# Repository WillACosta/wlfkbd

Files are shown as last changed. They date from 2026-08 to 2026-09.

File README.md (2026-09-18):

## The Wolf Split Keyboard

> [!WARNING]
> **Work In Progress (WIP)**: This project is currently under active development.

> 3×6 (+2 outer-pinky) Split Keyboard · 3 Thumb Keys · All 1U · MX Compatible

The **WᛝLF Keyboard**, or simply **wlfkbd**, is a 40-key keyboard
featuring only 2 outer-pinky keys to improve ergonomics. This keyboard takes inspiration from well-known open-source keyboards such as "Corne", "Klor", and "Delta/Omega".

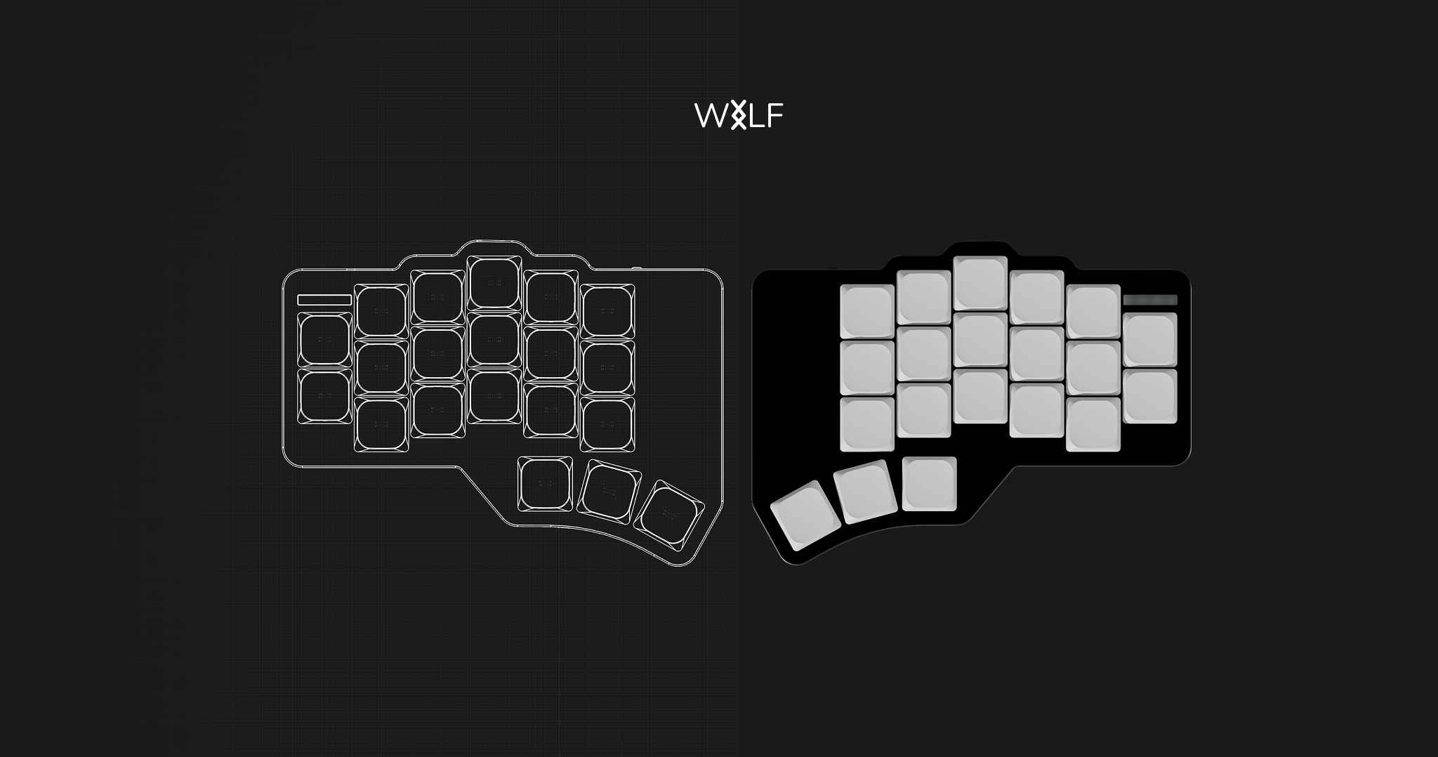
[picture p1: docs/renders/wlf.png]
"The Wolf Keyboard Render"


### Core Features

- Wireless BLE (XIAO nRF52840).
- Ultra-low-profile build (<= 8mm).
- Low-profile switches and keycaps.
- Compatible with MX-Standard and Gateron KS33/3.0 Low-Profile switches.
- Good battery life (>=700mAh).
- Minimalist and industrial design.
- Aluminum case.
- MX-Spacing.
- White backlight.
- RGB Status LEDs.

> For details about the features, head to the [specs module](./docs/specs/)

## Firmware & Keymap

The firmware for The Wolf is powered by [ZMK](https://zmk.dev/) and is maintained in its dedicated repository: **[WillACosta/zmk-config-wlf](https://github.com/WillACosta/zmk-config-wlf)**

This repository links the firmware as a Git submodule under [`firmware/`](https://github.com/WillACosta/zmk-config-wlf). To clone both the hardware designs and firmware together:

```bash
git clone --recurse-submodules https://github.com/WillACosta/wlfkbd.git
```

## Layout Overview

| Zone | Columns | Rows | Keys/half | Notes |
|---|---|---|---|---|
| Matrix | 6 (outer → inner) | 3 (bottom, home, top) | 17 | Outer column skips bottom row (2 keys only) |
| Thumb | 3 (inner, home, outer) | 1 | 3 | Splayed arc, anchored below index |
| **Total** | | | **20** | **40 keys full board** |

### Column Stagger Profile

```
         outer  pinky  ring   middle  index  inner
stagger:   —    +u/2   +u/4   +u/4   −u/4   −u/4
mm:        0    +9.525 +4.763 +4.763 −4.763 −4.763
```

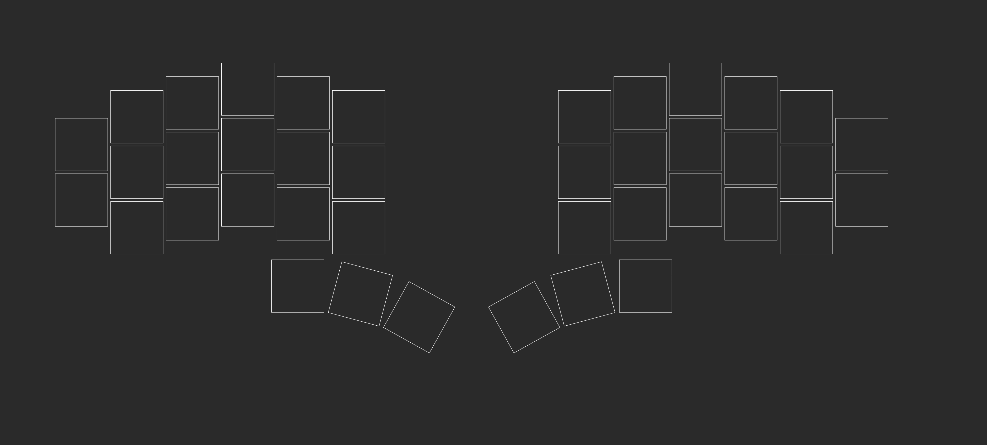
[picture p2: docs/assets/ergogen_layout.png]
"Ergogen wlfkbd Layout"


**Thumb Cluster Geometry**

| Key | Splay | Spread | Stagger | Effective rotation |
|-----|---|---|---|---|
| thumb_inner | 0° | u (19.05mm) | 0mm | 0° |
| thumb_home | −15° | u+2.5 (21.55mm) | −2.7mm | −15° |
| thumb_outer | −14° | u+2.5 (21.55mm) | −2.5mm | −29° |

The thumb cluster anchors at `matrix_index_bottom` with a `[-0.1u, -1.30u]` offset, placing it slightly left and well below the index column — a natural resting position for the thumb.

> See the Ergogen [config file here](./keyboard/ergogen/config.yml) (used only for the layout diagram)

## Motivations

After stepping into the rabbit hole of "Custom Split Keyboards", I found myself fascinated by this new world of different keyboard layouts, techniques, and a lot of fun!

I have used and own some beloved models created by incredible people, including:

- [Corne](https://github.com/foostan/crkbd)
- [Klor](https://github.com/GEIGEIGEIST/KLOR)
- [Delta/Omega](https://github.com/unspecworks/delta-omega)
- [Lily58](https://github.com/kata0510/Lily58)

The Corne is my favorite keyboard out there (you may notice some similarities between the wlfkbd and crkbd).

Still, I was missing something—that little thing that would improve my experience with the keyboard. Then I started testing different layouts on paper and came up with the layout shown earlier. I even used [Ergo Pad](https://pashutk.com/ergopad/) to find the most comfortable way of typing for my long fingers.

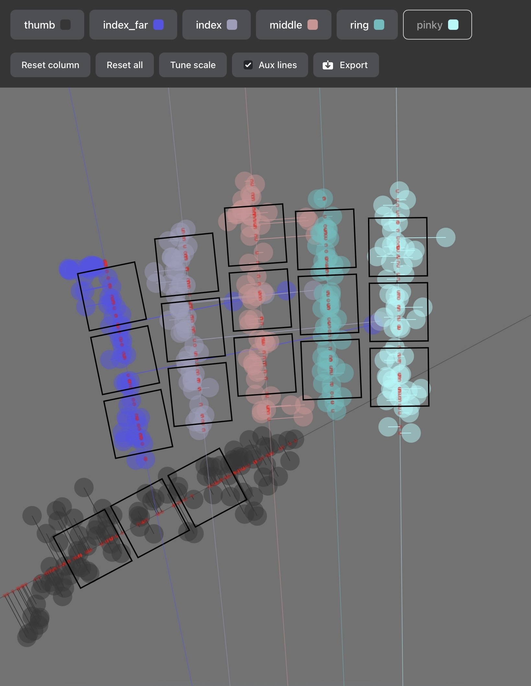
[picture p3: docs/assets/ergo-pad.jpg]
"Ergo-Pad layout tester"


### Features

I'm very fond of good, minimal design, so I've taken inspiration from Apple products, especially the [Magic Keyboard](https://www.ifixit.com/Teardown/Magic+Keyboard+Teardown/50995) and [Magic Trackpad](https://www.ifixit.com/Teardown/Magic+Trackpad+2+Teardown/51032).

I really enjoy the white backlight of the built-in Mac keyboard, so I wanted to implement this in the first revision. Even though I only use the backlight occasionally, it's a nice-to-have for me.

The major feature I present here is the status LED on top of the outer-pinky column. It's something that I really wanted to have in previous keyboards but hadn't.

Take a look at the current 3D render of the keyboard:

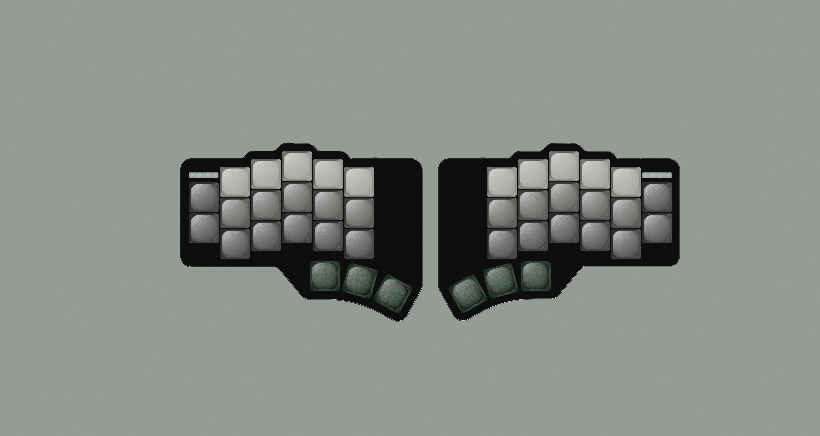
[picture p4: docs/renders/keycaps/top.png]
3D render for the wlfkbd


> For more pictures head to the [render gallery](./docs/renders/)

## Why "The WᛝLF"?

I really enjoy the symbolism of Wolves, it reminds me of the raw aspect of being human and a strong connection with nature and solitude. Regarding the Norse rune, the "Inguz", it represents "transitions", "new beginnings", "a force of will", etc. I have it tattooed on my right arm, so it's also a personal reference.

## PCB Design

The PCB was built to be ordered already assembled. This means that all components are SMD, so while you may be able to solder them by hand, it requires solid soldering experience.

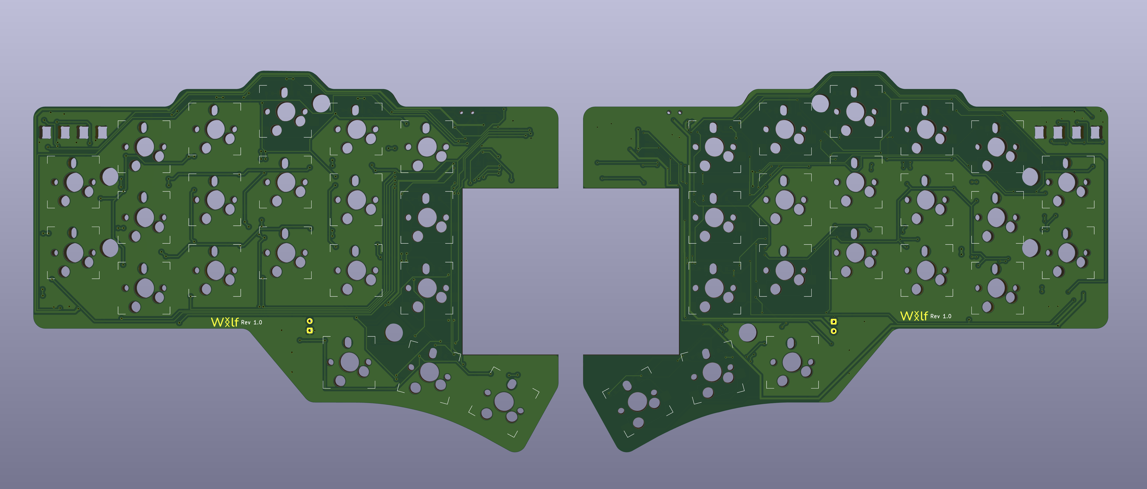
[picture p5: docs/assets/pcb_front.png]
PCB render front

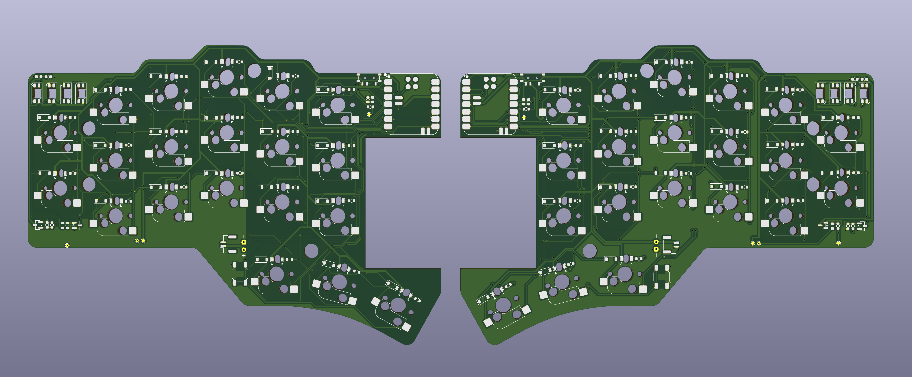
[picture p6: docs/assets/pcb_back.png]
PCB render back


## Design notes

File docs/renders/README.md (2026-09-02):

# Render Gallery

A unified visual gallery of 3D renders, views, and wireframes for the **wlfkbd** (Wolf Split Keyboard).

## Perspectives & Angles

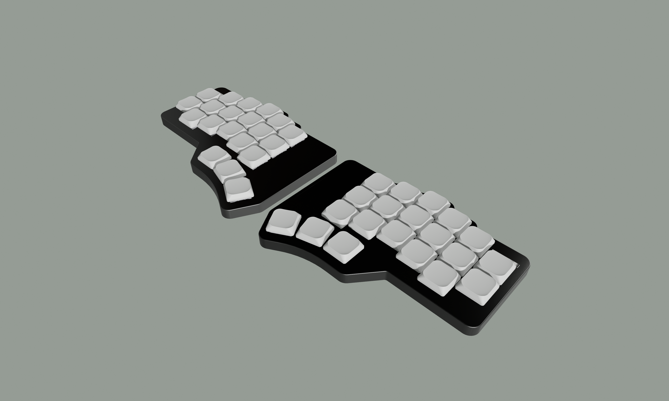
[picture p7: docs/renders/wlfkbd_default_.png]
Default View


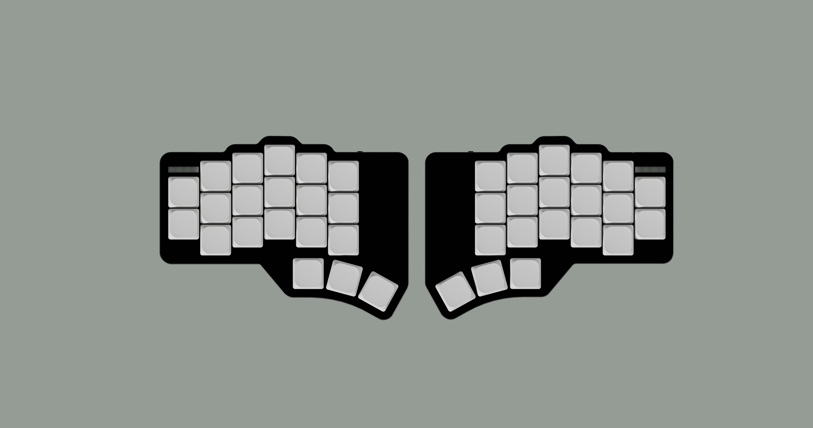
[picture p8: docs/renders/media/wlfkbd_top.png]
Top View


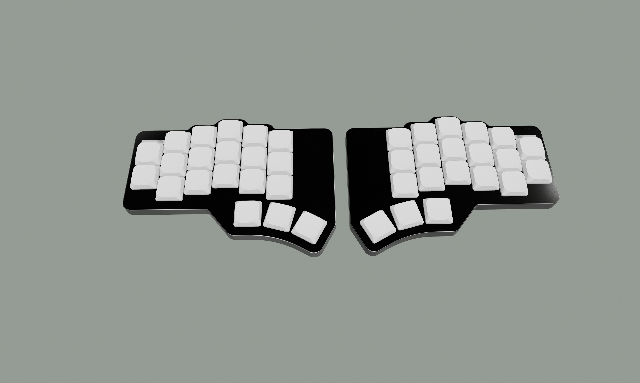
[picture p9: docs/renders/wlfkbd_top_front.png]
Top Front View


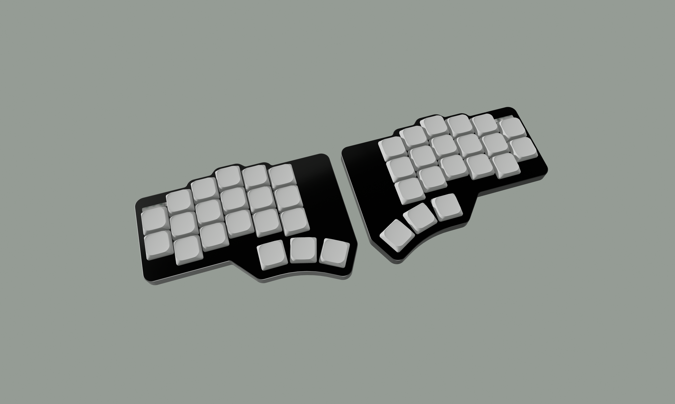
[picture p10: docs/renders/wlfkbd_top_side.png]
Top Side View


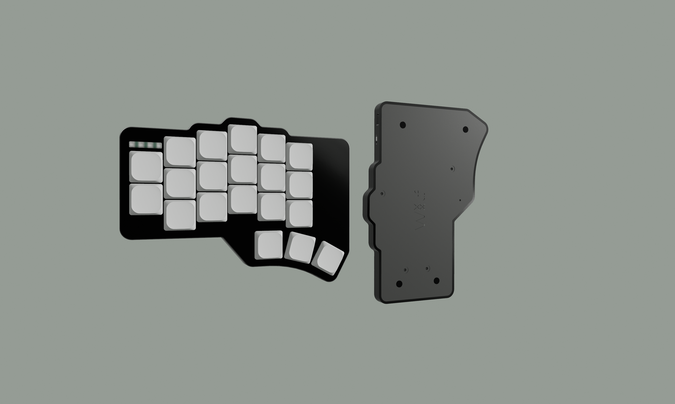
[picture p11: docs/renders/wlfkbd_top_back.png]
Top Back View


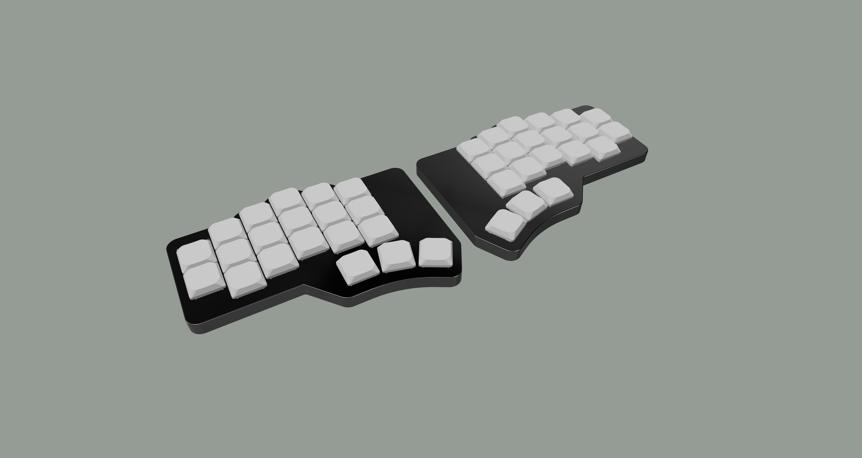
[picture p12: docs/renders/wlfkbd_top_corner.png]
Top Corner View


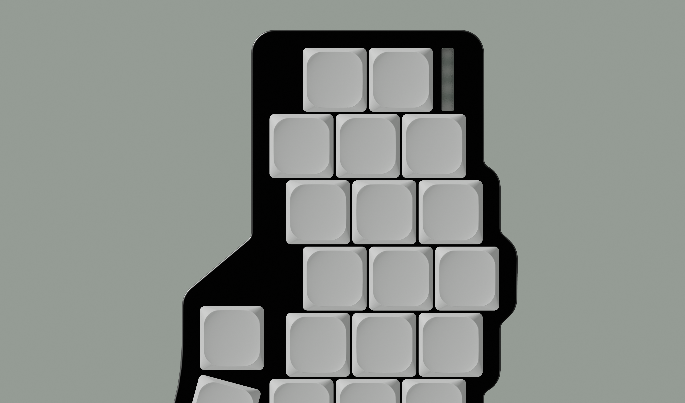
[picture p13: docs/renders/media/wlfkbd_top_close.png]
Top Close View


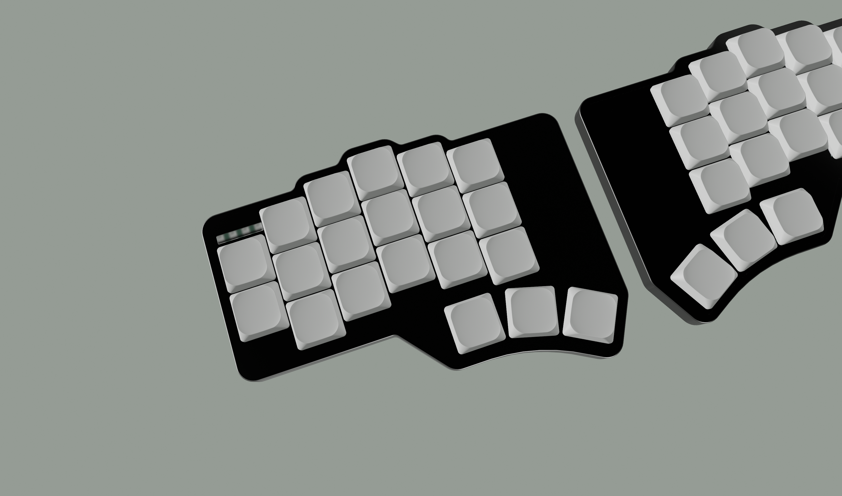
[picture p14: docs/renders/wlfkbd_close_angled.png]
Close Angled View


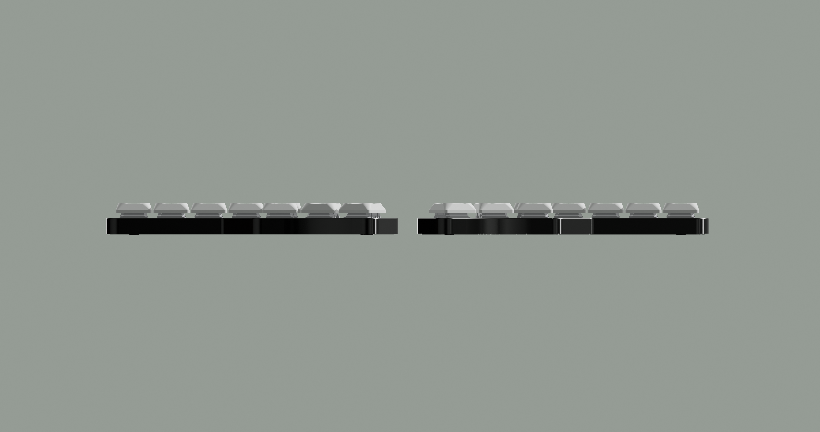
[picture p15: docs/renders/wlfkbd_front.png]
Front View


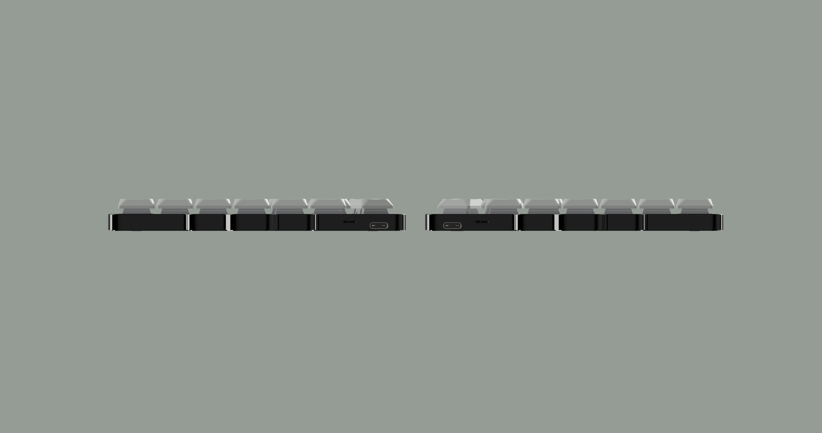
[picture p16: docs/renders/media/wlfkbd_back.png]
Back View


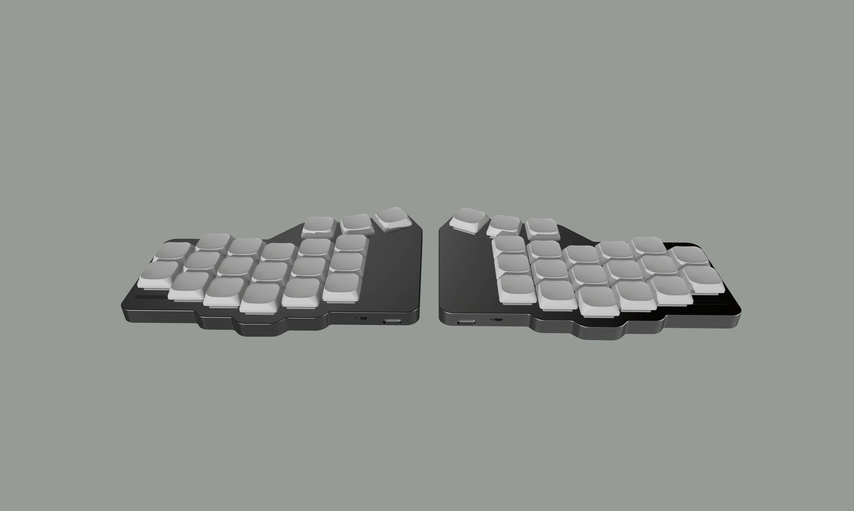
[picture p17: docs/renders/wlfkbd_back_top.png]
Back Top View


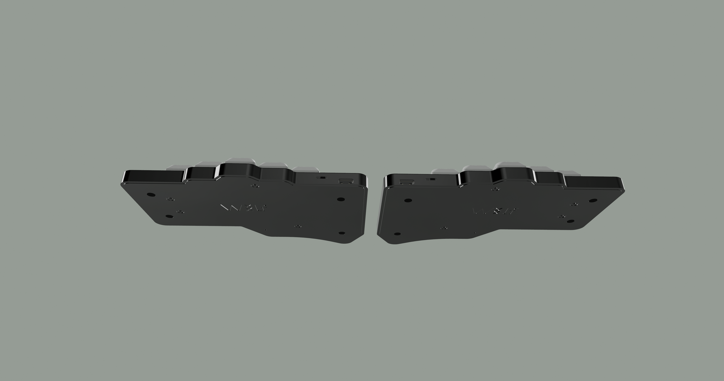
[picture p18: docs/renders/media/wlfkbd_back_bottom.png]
Back Bottom View


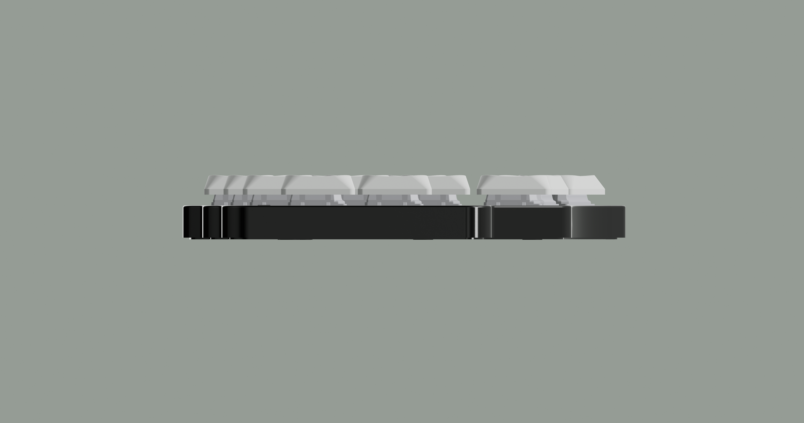
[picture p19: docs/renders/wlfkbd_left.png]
Left View


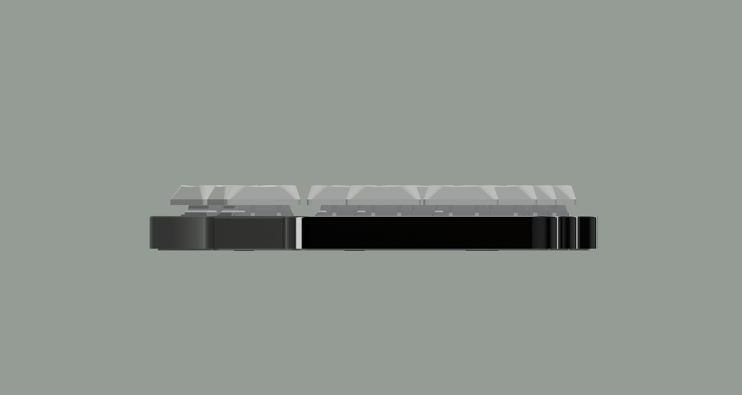
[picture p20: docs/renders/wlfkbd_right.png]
Right View


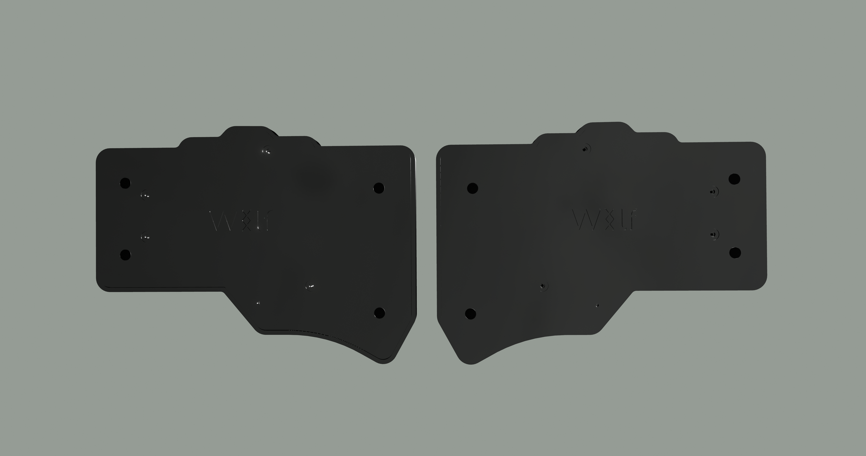
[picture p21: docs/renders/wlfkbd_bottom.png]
Bottom View


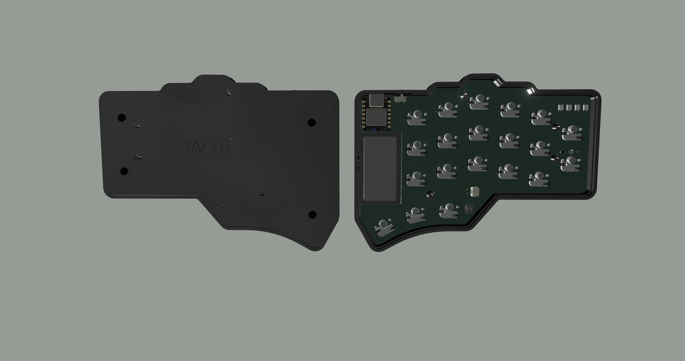
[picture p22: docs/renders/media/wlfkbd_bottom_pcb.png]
Bottom PCB View


## Wireframes

3D Wireframe

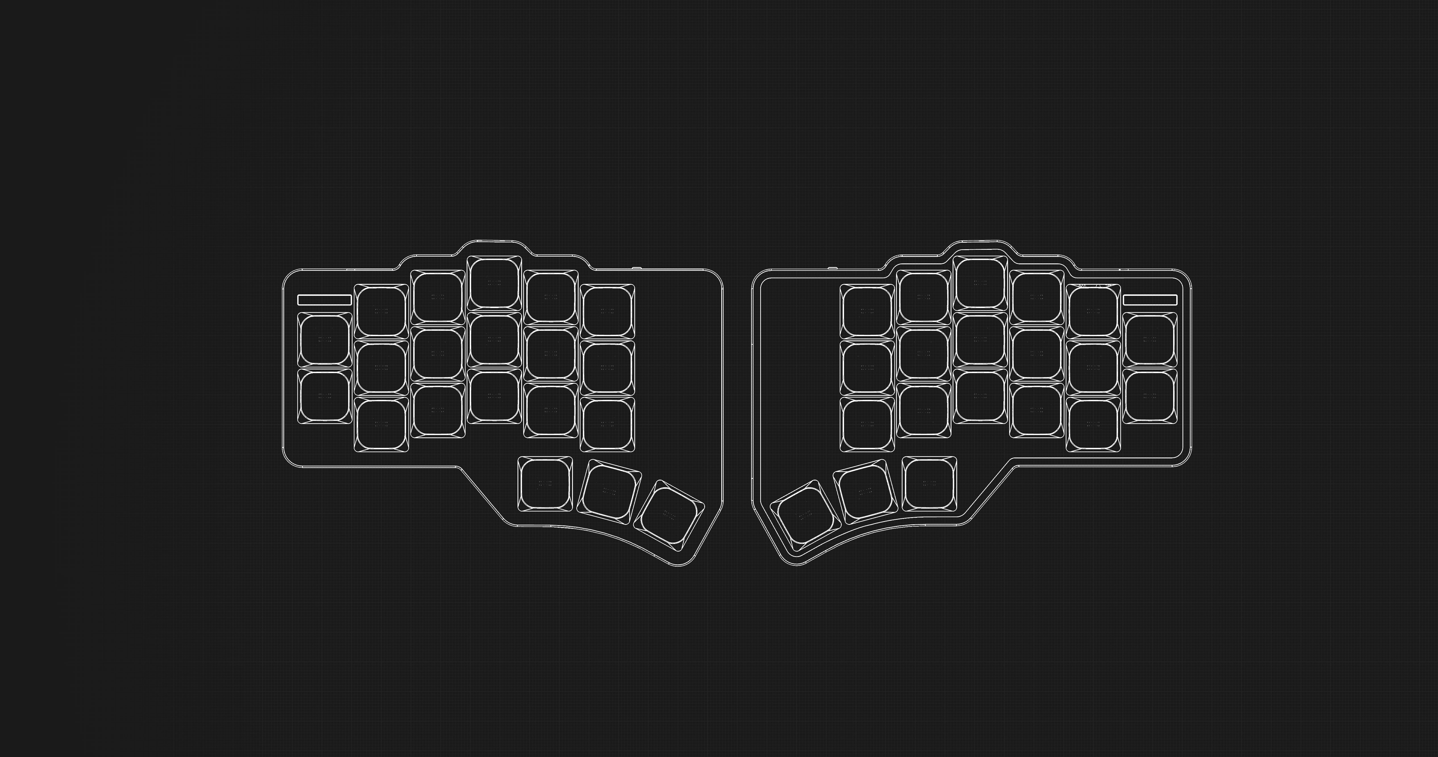
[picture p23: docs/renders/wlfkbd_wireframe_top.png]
Top Wireframe


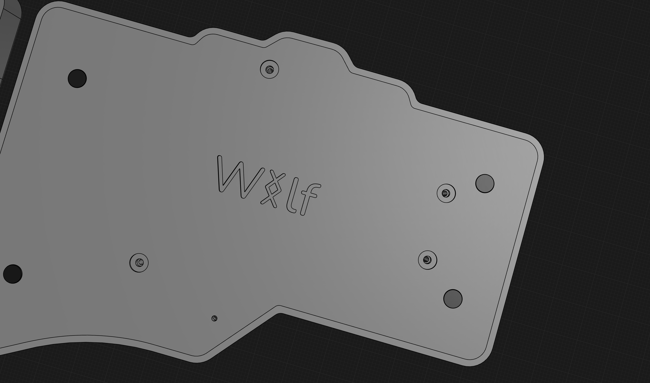
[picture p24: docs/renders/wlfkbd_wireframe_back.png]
Back Wireframe


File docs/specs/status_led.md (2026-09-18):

## LED status indicators behavior spec

This document shortly explain the definitions for the LED status indicators for the Wlf keyboard. Here are some approaches that I found on the community.

## Requirements

- Minimalist and discret design: LEDs are invisible when off.
- 4 individual RGB lights (each side).
- **Statuses**: Bluetooth Profiles, Battery, and Split link.

## Addressable RGB LEDs using SK6812 Mini-E

- LED Strip: SK6812 addressable LEDs (1-4 LEDs recommended)
- Power: 5V preferred (3.3V compatible), appropriate current capacity
- Data Connection: Single GPIO pin connected to strip's DI (Data In)
- SPI Interface: Available SPI peripheral (uses MOSI pin for data)

> Addressable LED implementations here on [hitsmaxft/zmk-rgbled-widget](https://github.com/hitsmaxft/zmk-rgbled-widget#adding-support-in-custom-boardsshields).

### LED status behaviors

Minimalist and easy-to-remember colors (Nuphy inspired).

**Connection**

🔵🔵🔵 = [Solid] (Left) Host connected
🔵🔵🔵 = [Breathing] (Left) Host disconnected
🔵🔵🔵 = [Blinking] (Left) Advertising

🔵🔵🔵 = [Solid] (Right) Split Linked
🔵🔵🔵 = [Breathing] (Right) Split disconnected

⚪⚪⚪ = [Solid] (Left) USB connected

**Battery**

🟢🟢🟢 = [Solid] (Left/Right) 80 - 100%
🟡🟡⚫ = [Solid] (Left/Right) 40 - 79%
🔴⚫⚫ = [Solid] (Left/Right) < 40%

🟢🟢🟢 = [Breathing] (Left/Right) Charging

**Layers**

Base = None
Symbol = None
Number = None
Media = 🔵 (Cyan)
Dev = 🟢 (Green)
Extra = 🟣

LEDs are activated in two moments:

- On boot it shows connection state and battery level, a solid color for 2s then turn off;
- On demand by using specific combos;

When not in use they are turned off to energy saving purpose.

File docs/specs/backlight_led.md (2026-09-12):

# Wlf Keyboard — White Backlight System

## Overview

Wlf uses a **single-zone white LED backlight** inspired by Apple's Magic Keyboard and MacBook keyboards. The objective is to provide a subtle, elegant, and battery-efficient backlight while keeping the hardware simple, inexpensive, and easy to manufacture using JLCPCB SMT Assembly.

- White-only backlight
- Single lighting zone
- PWM-controlled AO3400A MOSFET
- One resistor per LED
- LEDs powered directly from the battery (`VBAT`)
- Dedicated `LED_VCC` power rail
- 10uF + 100nF local decoupling
- No LED driver
- Fully compatible with ZMK
- Optimized for wireless battery-powered operation
- Easy to manufacture with JLCPCB SMT Assembly

This design closely follows the philosophy used in premium commercial keyboards: minimal hardware complexity, excellent battery life, and a clean, understated lighting experience.

The entire backlight is controlled as a **single lighting zone**, allowing global brightness adjustment through PWM without requiring a dedicated LED driver.

### Why No LED Driver?

Wlf Rev. A intentionally avoids dedicated LED driver ICs (IS31FL37xx family).

Instead, all LEDs are switched simultaneously using a single PWM-controlled MOSFET.

#### Advantages

- Only one GPIO required
- Very small BOM
- Extremely simple schematic
- Easy PCB routing
- Excellent battery life
- Minimal firmware complexity
- Fully supported by ZMK PWM

#### Trade-offs

Supported:

- ✅ Backlight ON/OFF
- ✅ Global brightness control
- ✅ PWM dimming
- ✅ Fade in / Fade out
- ✅ Auto-off after inactivity

Not supported:

- ❌ Per-key brightness
- ❌ Reactive typing
- ❌ Ripple animations
- ❌ RGB effects
- ❌ Multiple lighting zones

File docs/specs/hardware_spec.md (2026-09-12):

## Hardware Definitions

This document describes the hardware decisions and choices for the Wlf Keyboard.

## Must Have

- Usage of "Panelized Non-Reversible" PCB (costs saving and easy routing).
- Seeed Studio XIAO nRF52840 Plus (20 GPIO).

## WIP

- RGB LEDs for status indicador ([WIP](./led_status_system.md)).
- Add tiny magnets on the side to "lock" the halves and use "unibody-like" (alternative to the pogo-pins).
- Add tiny magnets on the bottom to secure halves during transport and easy travel.

## Research

These are some ideas, but are not yet solid for implementation. Needs deep research.

- Pogo Pins support for charging the peripheral (while central is connected on power).
- NFC for wireless charging

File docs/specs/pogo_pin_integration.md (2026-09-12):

> This is currently a disabled feature, this document exists only for future reference.

```mermaid
flowchart LR
    subgraph Left["Main / Left Keyboard Half - Schema v2 (Diode Added)"]
        L_XIAO["XIAO nRF52840"]
        L_BAT("LiPo Battery")
        L_DIODE["Schottky Diode (e.g. B5819WS)"]
        L_POGO["4-Pin Pogo Connector"]
        L_R1["330Ω Resistor"]
        L_R2["330Ω Resistor"]

        L_XIAO ---|BAT+| L_BAT
        L_XIAO ---|5V / VBUS| L_DIODE
        L_DIODE ---|Cathode → Pin 1| L_POGO
        L_XIAO ---|GND → Pin 2| L_POGO

        L_XIAO ---|GPIO TX| L_R1
        L_R1 ---|Pin 3| L_POGO

        L_XIAO ---|GPIO RX| L_R2
        L_R2 ---|Pin 4| L_POGO
    end

    subgraph Right["Peripheral / Right Keyboard Half"]
        R_POGO["4-Pad Target Contact"]
        R_XIAO["XIAO nRF52840"]
        R_BAT("LiPo Battery")
        R_R1["330Ω Resistor"]
        R_R2["330Ω Resistor"]

        R_POGO ---|Pad 1 → 5V / VBUS| R_XIAO
        R_POGO ---|Pad 2 → GND| R_XIAO

        R_POGO ---|Pad 3| R_R1
        R_R1 ---|GPIO TX| R_XIAO

        R_POGO ---|Pad 4| R_R2
        R_R2 ---|GPIO RX| R_XIAO

        R_XIAO ---|BAT+| R_BAT
    end

    L_POGO ===|Physical Magnetic Mating| R_POGO
```

```mermaid
flowchart LR

%% =====================================================================
%% LEFT HALF
%% =====================================================================

subgraph LEFT["Main / Left Half"]

    USB["USB_VBUS"]
    PF["Polyfuse (Optional)"]
    D["Schottky Diode"]
    TVS5L["5V TVS"]

    MCU_L["XIAO nRF52840 Plus"]
    BAT_L["LiPo Battery"]

    TVSD_L["2-Channel TVS"]
    R1["33Ω"]
    R2["33Ω"]

    POGO_L["4-Pin Pogo Connector"]

    BAT_L <-->|BAT+/BAT-| MCU_L

    USB --> PF
    PF --> D
    D --> POGO_L

    POGO_L --- TVS5L
    TVS5L --> GNDL["GND"]

    MCU_L --> R1
    R1 --> TVSD_L
    TVSD_L --> POGO_L

    MCU_L --> R2
    R2 --> TVSD_L

    MCU_L --- GNDL
    GNDL --> POGO_L

end

%% =====================================================================
%% RIGHT HALF
%% =====================================================================

subgraph RIGHT["Peripheral / Right Half"]

    POGO_R["4-Pin Target Pads"]

    TVS5R["5V TVS"]
    TVSD_R["2-Channel TVS"]

    R3["33Ω"]
    R4["33Ω"]

    MCU_R["XIAO nRF52840 Plus"]
    BAT_R["LiPo Battery"]

    GNDR["GND"]

    BAT_R <-->|BAT+/BAT-| MCU_R

    POGO_R --> MCU_R

    POGO_R --- TVS5R
    TVS5R --> GNDR

    POGO_R --> TVSD_R
    TVSD_R --> R3
    R3 --> MCU_R

    TVSD_R --> R4
    R4 --> MCU_R

    POGO_R --> GNDR
    MCU_R --- GNDR

end

%% =====================================================================
%% MECHANICAL CONNECTION
%% =====================================================================

POGO_L ===|"Magnetic Pogo Interface"| POGO_R
```

## BOM

| Function | Recommended Part | Package | KiCad Footprint | Placement Rule | Routing Rule | Notes |
| --- | --- | --- | --- | --- | --- | --- |
| **Magnetic Pogo Connector** | Xinyangze **YZP0048-20048-04025-03** _(or equivalent 4-pin connector)_ | Vendor-specific | **Custom footprint** | **On the PCB edge**, aligned with the enclosure and magnets. | Keep `POGO_VBUS`, `POGO_GND`, `POGO_LINK_IO1`, and `POGO_LINK_IO2` as short as practical leaving the connector. | Verify mechanical clearance using the STEP model before manufacturing. |
| **Reverse Current Protection** | **B5819WS** | SOD-323 / SOD-123W _(manufacturer dependent)_ | `Diode_SMD:D_SOD-323` or matching package | **Near the USB/XIAO power input**, **not** near the pogo connector. | Route `USB_VBUS → Polyfuse → Schottky → POGO_VBUS`. | Prevents power from the pogo connector or battery from backfeeding into the USB supply. |
| **Overcurrent Protection (Optional)** | Polyfuse ~500 mA Hold _(e.g. 0ZCJ0050AF2E)_ | 1206 | `Fuse:Fuse_1206_3216Metric` | Immediately after the USB power source. | Place before the Schottky diode. | Optional, but recommended for a premium design to protect against shorts on the pogo interface. |
| **VBUS ESD Protection** | **SMF5.0A** | DO-219AB (SMF) | `Diode_SMD:D_SMF` | **As close as possible to the pogo connector.** | Connect **directly between `POGO_VBUS` and `GND`**. Use a **very short trace** and **dedicated GND via** beside the device. | First line of defense against ESD and transient surges on the charging pin. |
| **GPIO ESD Protection** | **TPD2E2U06DCKR** | SC70-3 (DCK) | `Package_TO_SOT_SMD:SOT-353_SC-70-3` | **Immediately beside the pogo connector.** | Signal flow should be: **Pogo → TVS → 33 Ω → MCU**. Connect GND with a **dedicated via** next to the GND pin. | Protects the exposed communication lines (`POGO_LINK_IO1`, `POGO_LINK_IO2`) from ESD. |
| **Series Resistors** | **33 Ω ±1%** | 0402 or 0603 | `Resistor_SMD:R_0402_1005Metric` _(or 0603)_ | **Near the MCU**, not the connector. | One resistor per communication line, placed **after the TVS** and **before the MCU GPIO**. | Improves signal integrity and limits transient current into the MCU. |

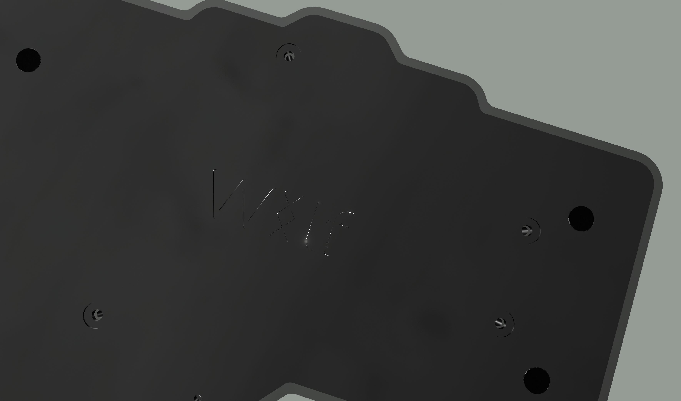
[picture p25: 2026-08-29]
docs/renders/media/wlfkbd_wireframe_back_3d.png

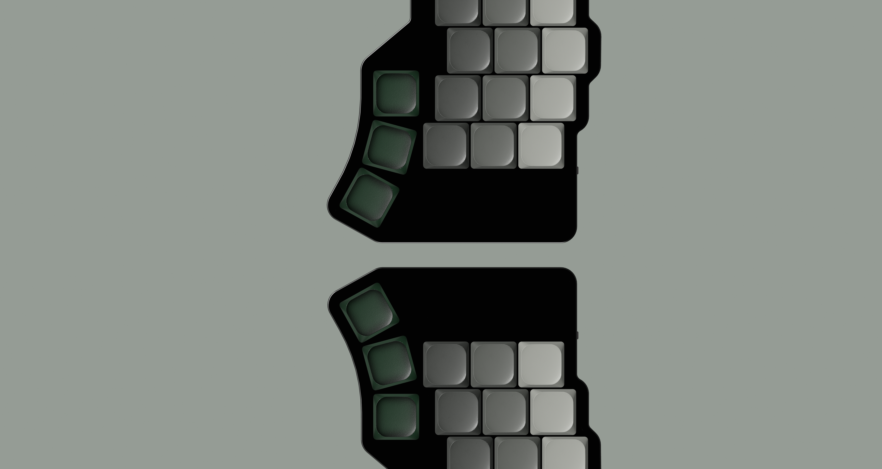
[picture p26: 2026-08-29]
docs/renders/keycaps/top_close_both.png

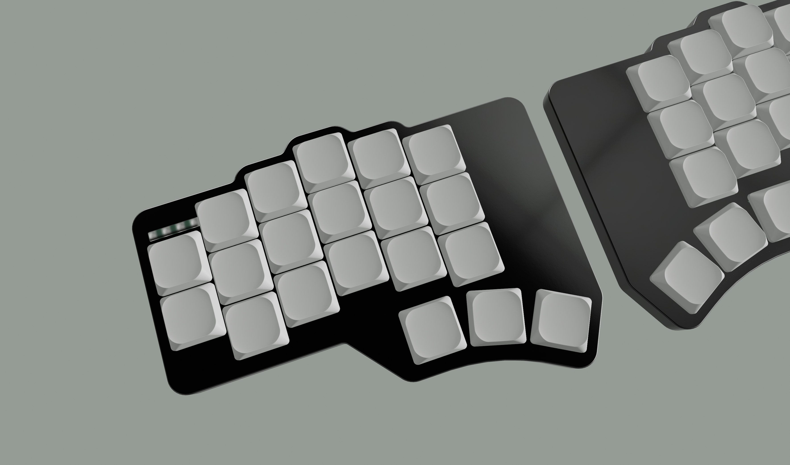
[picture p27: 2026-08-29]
docs/renders/media/wlfkbd_top_close_angled.png

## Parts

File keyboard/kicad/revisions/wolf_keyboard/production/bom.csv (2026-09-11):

Designator | Footprint | Quantity | Value | LCSC Part #
C1, C3, C5_R1, C7_R1 | 0603 | 4 | 10uF - 10V | C19702
C2, C4, C6_R1, C8_R1 | 0603 | 4 | 100nF - 50V | C1591
D1, D10, D11, D12, D13, D14, D15, D16, D17, D18, D19, D2, D20, D3, D4, D5, D6, D61_R1, D62_R1, D63_R1, D64_R1, D7, D72_R1, D73_R1, D74_R1, D75_R1, D8, D81_R1, D82_R1, D83_R1, D84_R1, D85_R1, D86_R1, D87_R1, D88_R1, D89_R1, D9, D90_R1, D91_R1, D92_R1 | D_SOD-123 | 40 | 1N4148W | C2099
D21, D22, D23, D24, D47_R1, D48_R1, D50_R1, D52_R1 | LED_SK6812MINI-E_3.2x2.8mm_P1.5mm_ReverseMount | 8 | SK6812MINI-E | C5149201
D25, D26, D29, D30, D31, D32, D33, D34, D35, D36, D37, D38, D39, D40, D41, D42, D43, D44, D45, D46, D53_R1, D54_R1, D55_R1, D56_R1, D57_R1, D58_R1, D59_R1, D60_R1, D65_R1, D66_R1, D67_R1, D68_R1, D69_R1, D70_R1, D71_R1, D76_R1, D77_R1, D78_R1, D79_R1, D80_R1 | LED_MHT151WDT | 40 | LED | C401114
JST1, JST2_R1 | JST_GH_SM02B-GHS-TB_1x02-1MP_P1.25mm_Horizontal | 2 | Conn_01x02_Pin
PSW1, PSW2_R1 | SW_MSK12C02-HB | 2 | SW_SPDT | C778186
Q1, Q4_R1 | SOT-23 | 2 | AO3400A | C20917
Q2, Q3_R1 | SOT-23 | 2 | AO3407A | C5179536
R1, R10, R11, R12, R13, R14, R15, R16, R17, R18, R19, R2, R20, R21, R22, R25_R1, R26_R1, R27_R1, R28_R1, R29_R1, R3, R30_R1, R31_R1, R32_R1, R33_R1, R34_R1, R35_R1, R36_R1, R37_R1, R38_R1, R39_R1, R4, R40_R1, R41_R1, R42_R1, R43_R1, R44_R1, R7, R8, R9 | 0603 | 40 | 1K | C21190
R706, R708_R1, R710, R713_R1 | 0603 | 4 | 100R | C22775
R707, R709_R1 | 0603 | 2 | 10k | C25804
R711, R714_R1 | 0603 | 2 | 100k | C25803
R712, R715_R1 | 0603 | 2 | 330R | C23138
RSW1, RSW2_R1 | SW_SPST_SKQG_WithStem | 2 | RSW1 | C115351
SW1, SW10, SW11, SW12, SW13, SW14, SW15, SW16, SW17, SW18, SW19, SW2, SW20, SW21, SW22, SW23, SW24, SW25, SW26, SW27, SW28, SW29, SW3, SW30, SW31, SW32, SW33, SW34, SW35, SW36, SW37, SW38, SW39, SW4, SW40, SW5, SW6, SW7, SW8, SW9 | KS-33B Hotswap 1u | 40 | SW_Push | C49352235
U1, U3 | XIAO-nRF52840-SMD | 2 | XIAO-nRF52840-SMD | C17209540

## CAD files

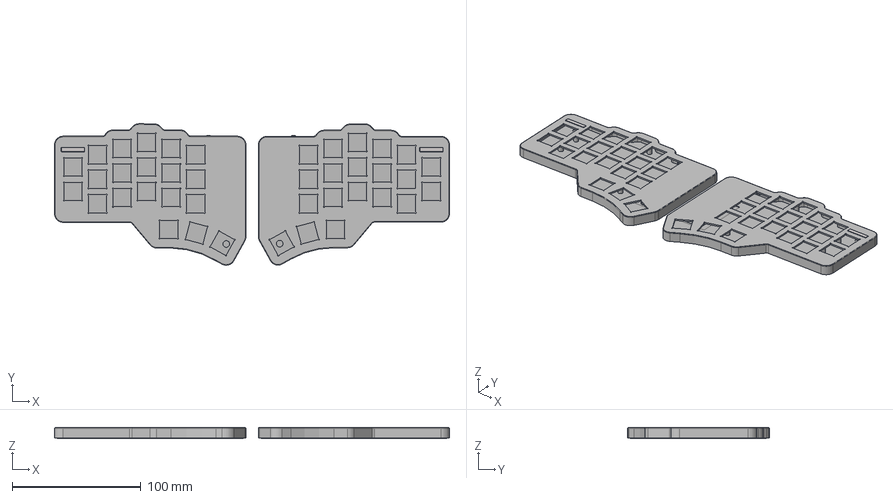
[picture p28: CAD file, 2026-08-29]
keyboard/case/projects/wlf_full_case.step
306.7 x 110.0 x 8.71 mm
Left
Right
Rubber Feets

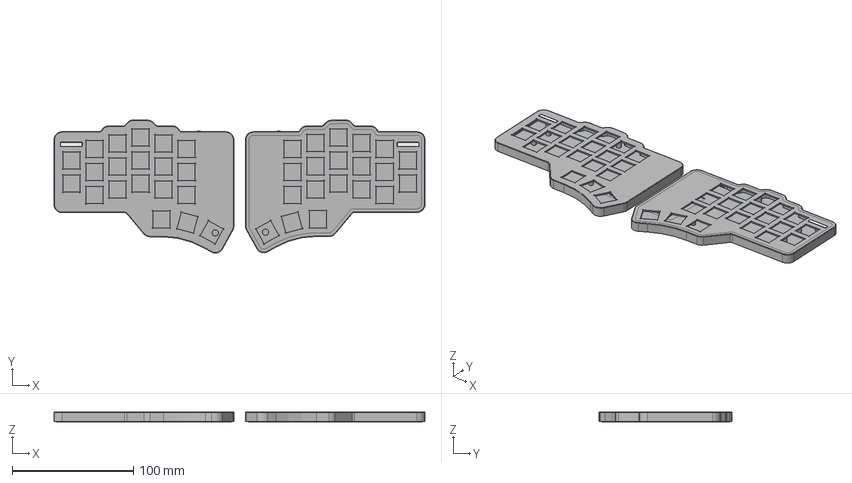
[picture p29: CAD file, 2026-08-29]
keyboard/case/wlf_full_case.step
306.6 x 110.0 x 8.63 mm
Left
Right
Rubber Feets

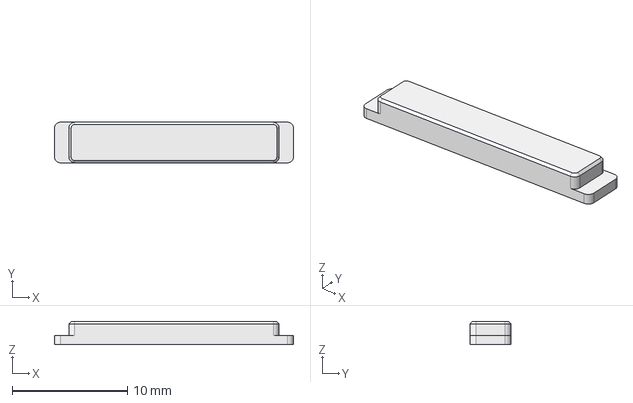
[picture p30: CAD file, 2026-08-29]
keyboard/case/wlf_led_diffuser.step
20.7 x 3.52 x 2.00 mm

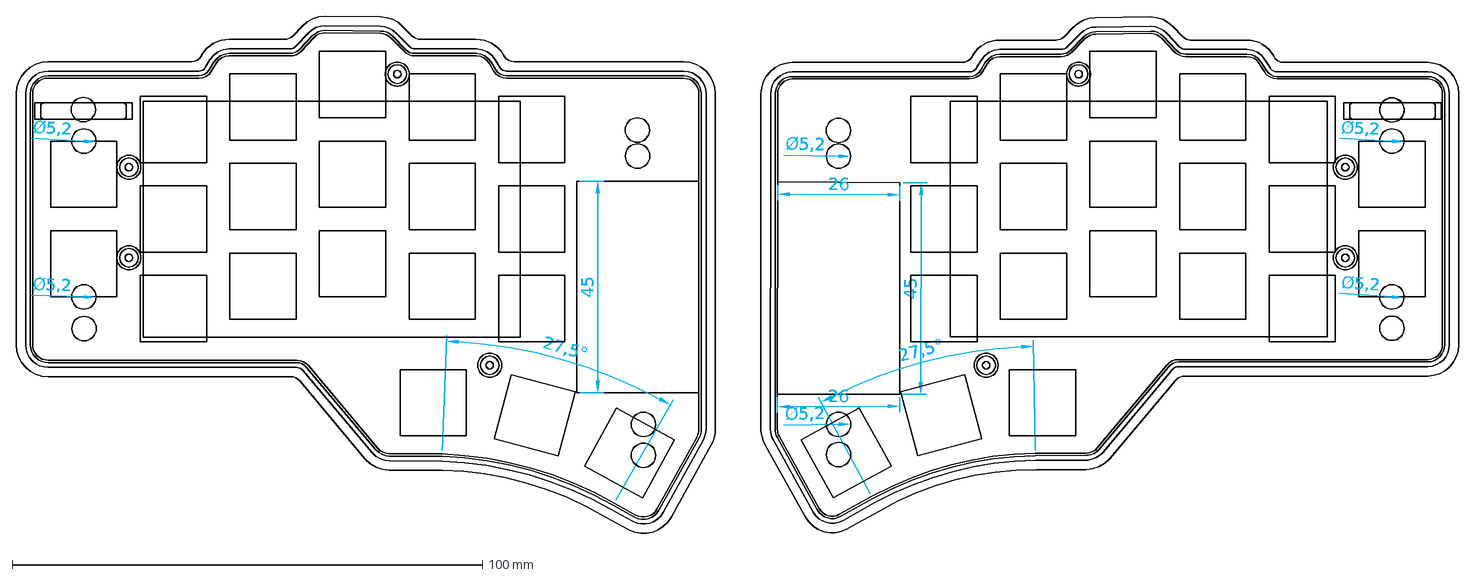
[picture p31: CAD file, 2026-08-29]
keyboard/case/projects/wlf_case_sketch.dxf
45
26
Ø5,2
27,5°

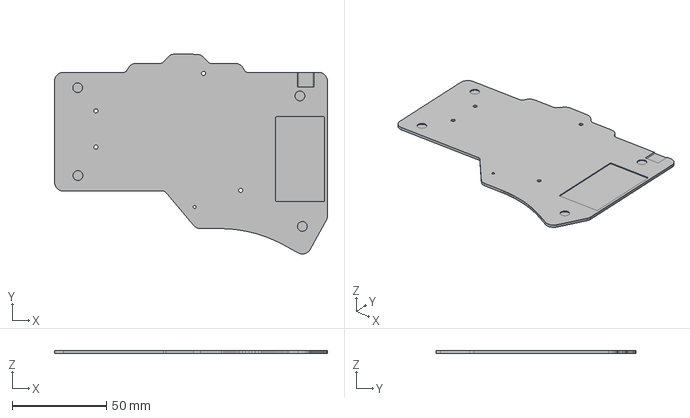
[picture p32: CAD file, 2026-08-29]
keyboard/case/wlf_left_bottom_plate.step
144.7 x 106.0 x 1.50 mm

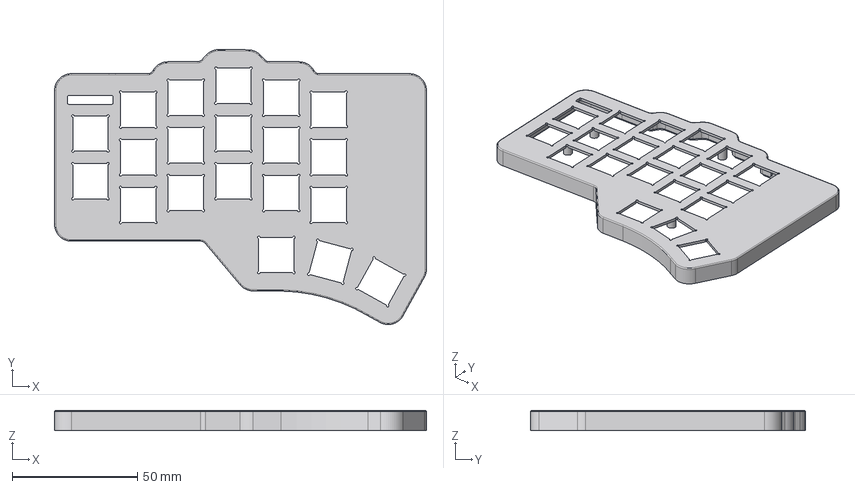
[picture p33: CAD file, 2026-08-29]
keyboard/case/wlf_left_top_case.step
148.7 x 110.0 x 8.00 mm

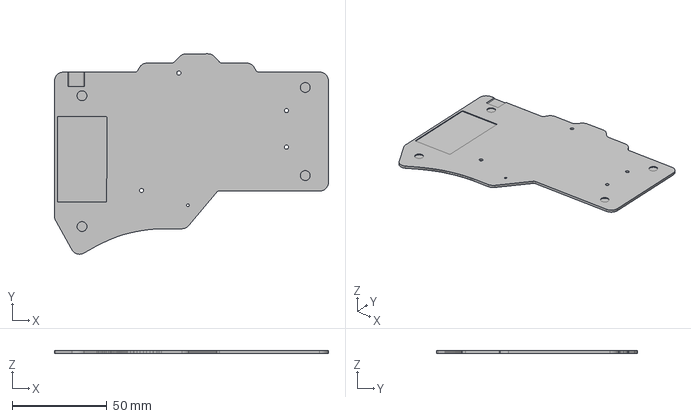
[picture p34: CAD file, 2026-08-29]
keyboard/case/wlf_right_bottom_plate.step
144.4 x 105.7 x 1.50 mm

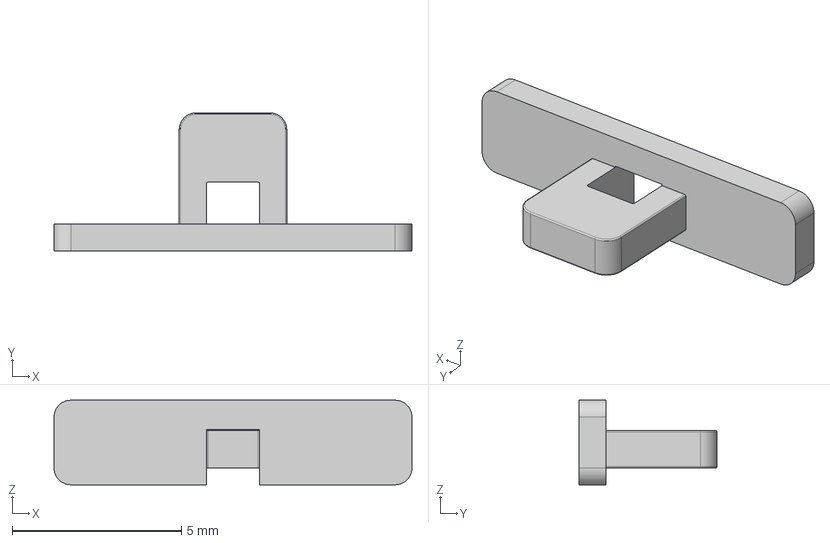
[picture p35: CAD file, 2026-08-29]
keyboard/case/wlf_pwr_switch_cap.step
10.6 x 4.09 x 2.50 mm

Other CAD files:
keyboard/case/wlf_right_top_case.step

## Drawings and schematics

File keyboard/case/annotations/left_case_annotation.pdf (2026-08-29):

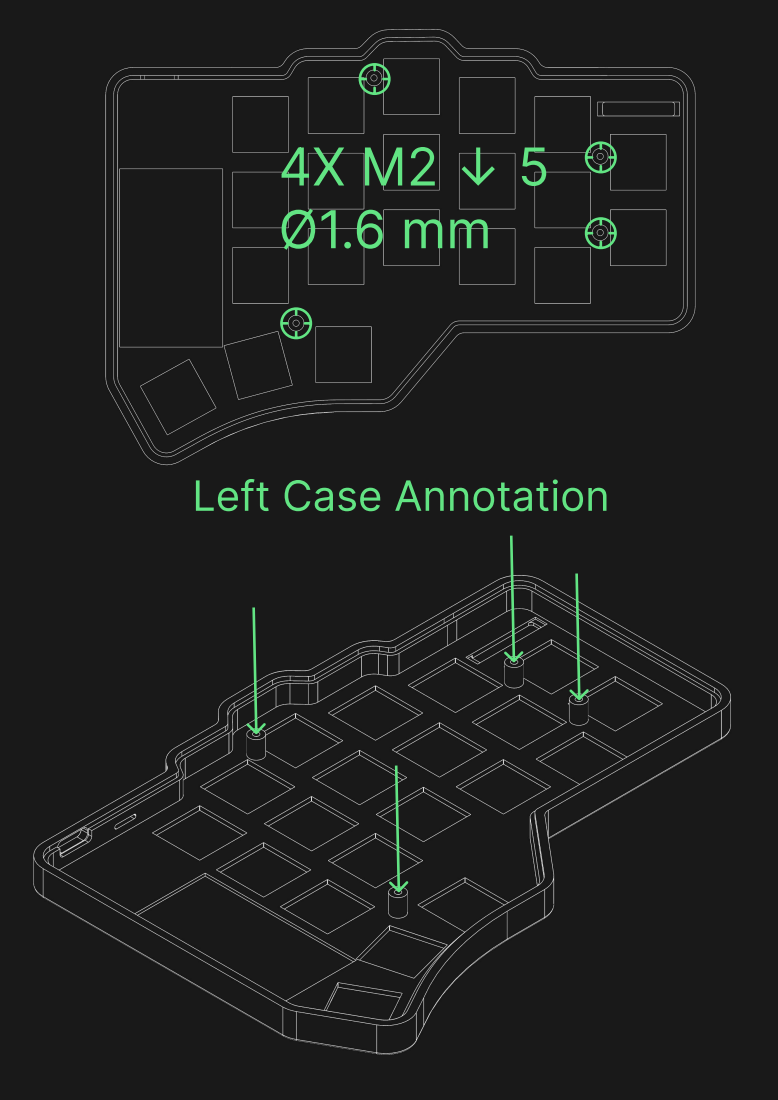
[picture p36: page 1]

Left Case Annotation

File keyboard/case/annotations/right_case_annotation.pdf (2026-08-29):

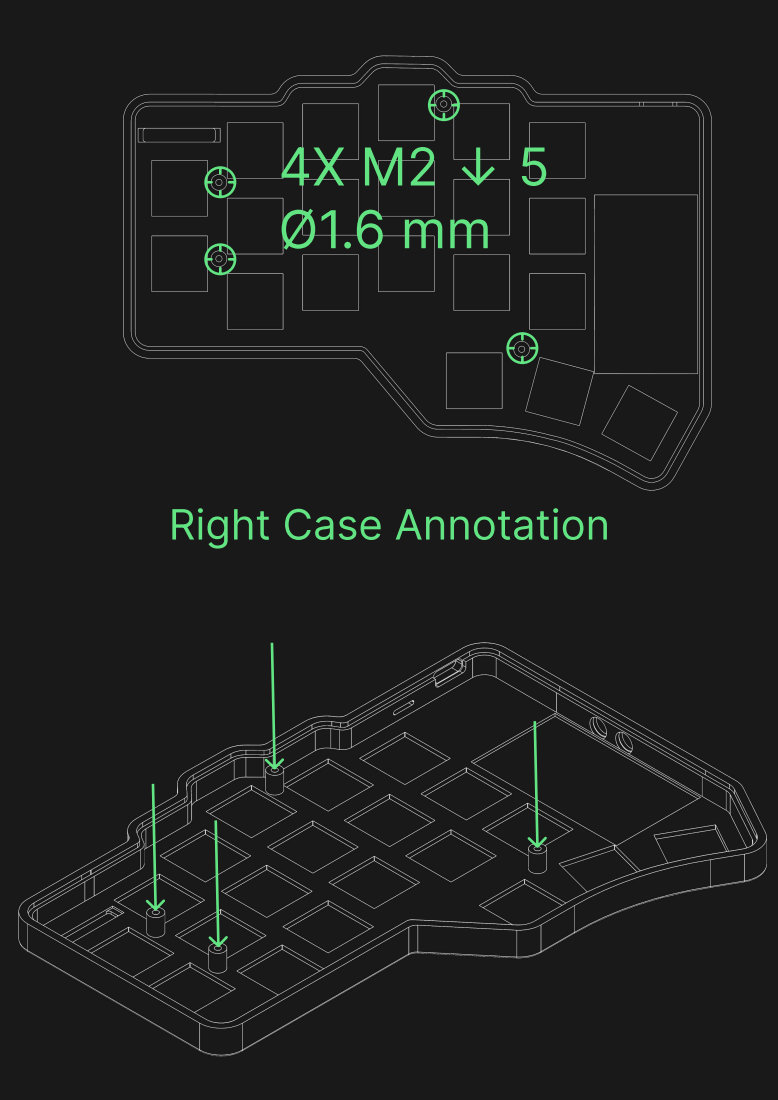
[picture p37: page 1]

Right Case Annotation

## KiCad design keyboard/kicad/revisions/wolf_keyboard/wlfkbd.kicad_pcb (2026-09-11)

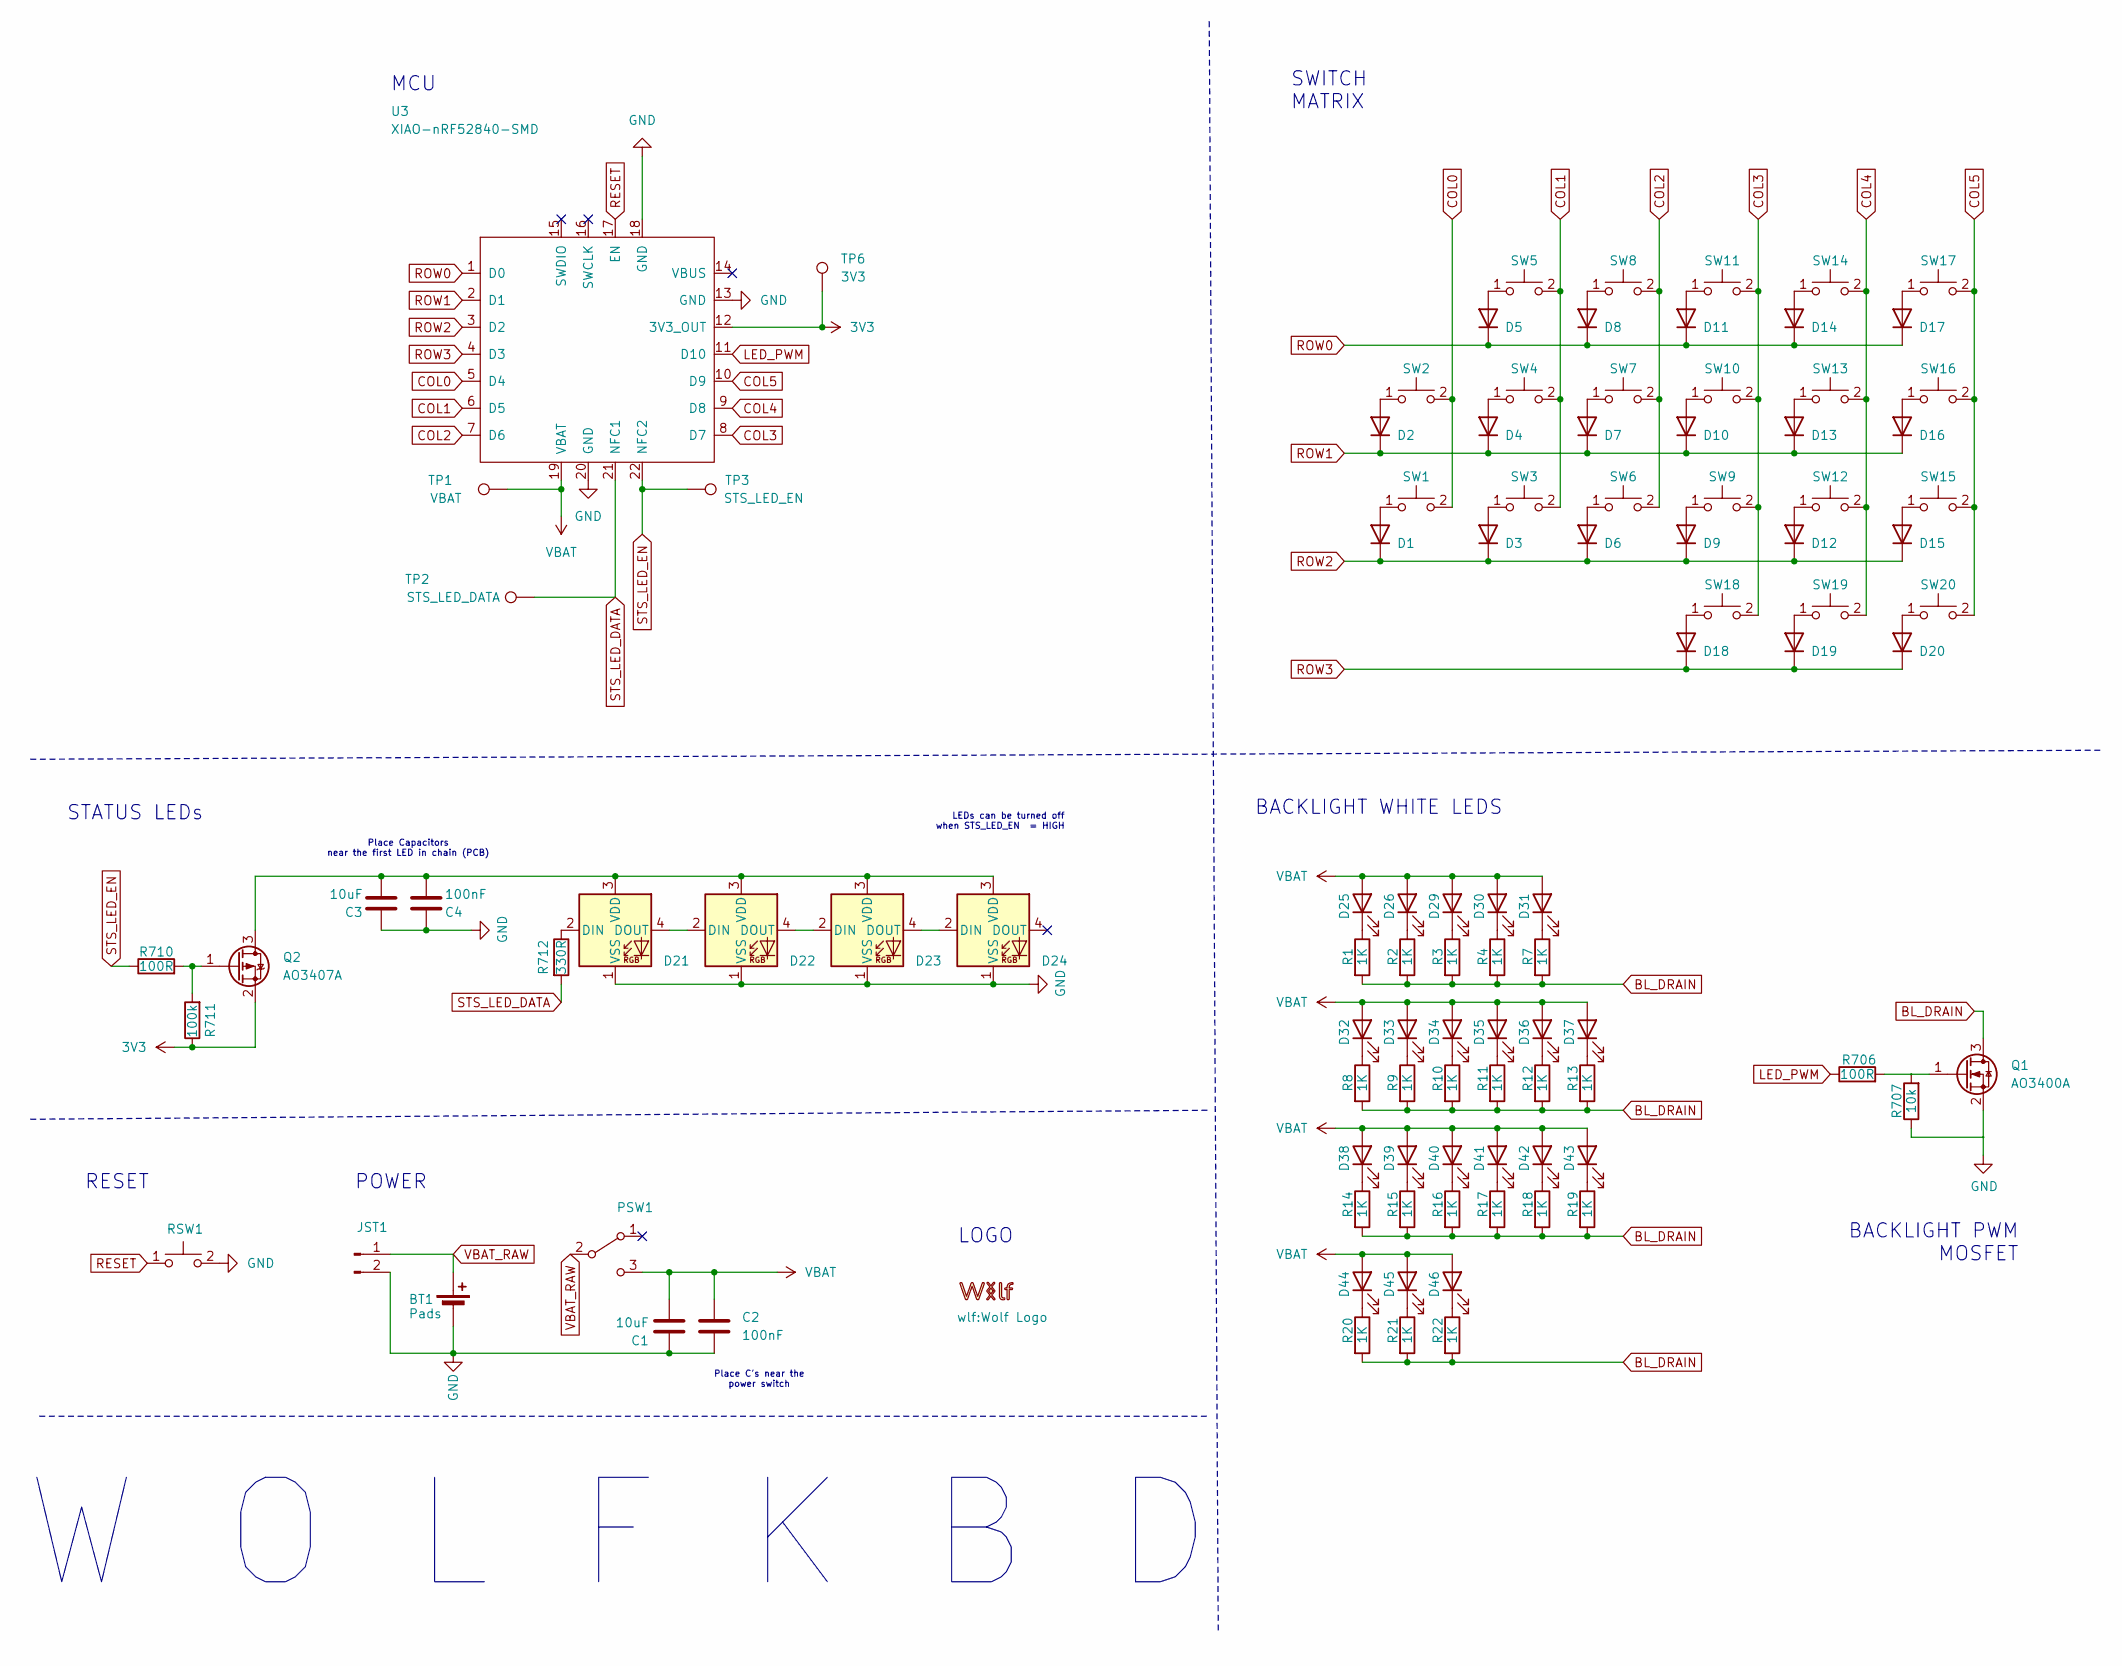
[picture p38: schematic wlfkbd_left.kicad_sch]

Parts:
BT1: Pads; Battery_Pad
C1, C3: 10uF; C_0603_1608Metric
C2, C4: 100nF; C_0603_1608Metric
D1, D2, D3, D4, D5, D6, D7, D8, D9, D10, D11, D12, D13, D14, D15, D16, D17, D18, D19, D20: 1N4148W; D_SOD-123
D21, D22, D23, D24: SK6812MINI-E; LED_SK6812MINI-E_3.2x2.8mm_P1.5mm_ReverseMount
D25, D26, D29, D30, D31, D32, D33, D34, D35, D36, D37, D38, D39, D40, D41, D42, D43, D44, D45, D46: LED; LED_MHT151WDT
JST1: Conn_01x02_Pin; JST_GH_SM02B-GHS-TB_1x02-1MP_P1.25mm_Horizontal
LOGO1: Wolf Logo
PSW1: SW_SPDT; SW_MSK12C02-HB
Q1: AO3400A; SOT-23
Q2: AO3407A; SOT-23; MPN AO3407A
R1, R2, R3, R4, R7, R8, R9, R10, R11, R12, R13, R14, R15, R16, R17, R18, R19, R20, R21, R22: 1K; R_0603_1608Metric
R706, R710: 100R; R_0603_1608Metric
R707: 10k; R_0603_1608Metric
R711: 100k; R_0603_1608Metric
R712: 330R; R_0603_1608Metric
RSW1: RSW1; SW_SPST_SKQG_WithStem
SW1, SW2, SW3, SW4, SW5, SW6, SW7, SW8, SW9, SW10, SW11, SW12, SW13, SW14, SW15, SW16, SW17, SW18, SW19, SW20: SW_Push; KS-33B Hotswap 1u
TP1: VBAT; TestPoint_Pad_D1.0mm
TP2: STS_LED_DATA; TestPoint_Pad_D1.0mm
TP3: STS_LED_EN; TestPoint_Pad_D1.0mm
TP6: 3V3; TestPoint_Pad_D1.0mm
U3: XIAO-nRF52840-SMD

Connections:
3V3: Q2.2 (S), R711.1, TP6.1 (1_1), U3.12 (3V3_OUT)
BL_DRAIN: Q1.3 (D), R1.2, R2.2, R3.2, R4.2, R7.2, R8.2, R9.2, R10.2, R11.2, R12.2, R13.2, R14.2, R15.2, R16.2, R17.2, R18.2, R19.2, R20.2, R21.2, R22.2
COL0: SW1.2, SW2.2, U3.5 (D4)
COL1: SW3.2, SW4.2, SW5.2, U3.6 (D5)
COL2: SW6.2, SW7.2, SW8.2, U3.7 (D6)
COL3: SW9.2, SW10.2, SW11.2, SW18.2, U3.8 (D7)
COL4: SW12.2, SW13.2, SW14.2, SW19.2, U3.9 (D8)
COL5: SW15.2, SW16.2, SW17.2, SW20.2, U3.10 (D9)
GND: BT1.2 (-), C1.2, C2.2, C3.1, C4.2, D21.1 (VSS), D22.1 (VSS), D23.1 (VSS), D24.1 (VSS), JST1.2, Q1.2 (S), R707.1, RSW1.2, U3.13 (GND), U3.18 (GND), U3.20 (GND)
LED_PWM: R706.1, U3.11 (D10)
unnamed: D1.2 (A), SW1.1
unnamed: D2.2 (A), SW2.1
unnamed: D3.2 (A), SW3.1
unnamed: D4.2 (A), SW4.1
unnamed: D5.2 (A), SW5.1
unnamed: D6.2 (A), SW6.1
unnamed: D7.2 (A), SW7.1
unnamed: D8.2 (A), SW8.1
unnamed: D9.2 (A), SW9.1
unnamed: D10.2 (A), SW10.1
unnamed: D11.2 (A), SW11.1
unnamed: D12.2 (A), SW12.1
unnamed: D13.2 (A), SW13.1
unnamed: D14.2 (A), SW14.1
unnamed: D15.2 (A), SW15.1
unnamed: D16.2 (A), SW16.1
unnamed: D17.2 (A), SW17.1
unnamed: D18.2 (A), SW18.1
unnamed: D19.2 (A), SW19.1
unnamed: D20.2 (A), SW20.1
unnamed: D21.2 (DIN), R712.1
unnamed: D21.4 (DOUT), D22.2 (DIN)
unnamed: C3.2, C4.1, D21.3 (VDD), D22.3 (VDD), D23.3 (VDD), D24.3 (VDD), Q2.3 (D)
unnamed: D22.4 (DOUT), D23.2 (DIN)
unnamed: D23.4 (DOUT), D24.2 (DIN)
unnamed: D25.1 (K), R1.1
unnamed: D26.1 (K), R2.1
unnamed: D29.1 (K), R3.1
unnamed: D30.1 (K), R4.1
unnamed: D31.1 (K), R7.1
unnamed: D32.1 (K), R8.1
unnamed: D33.1 (K), R9.1
unnamed: D34.1 (K), R10.1
unnamed: D35.1 (K), R11.1
unnamed: D36.1 (K), R12.1
unnamed: D37.1 (K), R13.1
unnamed: D38.1 (K), R14.1
unnamed: D39.1 (K), R15.1
unnamed: D40.1 (K), R16.1
unnamed: D41.1 (K), R17.1
unnamed: D42.1 (K), R18.1
unnamed: D43.1 (K), R19.1
unnamed: D44.1 (K), R20.1
unnamed: D45.1 (K), R21.1
unnamed: D46.1 (K), R22.1
unnamed: Q1.1 (G), R706.2, R707.2
unnamed: Q2.1 (G), R710.2, R711.2
RESET: RSW1.1, U3.17 (EN)
ROW0: D5.1 (K), D8.1 (K), D11.1 (K), D14.1 (K), D17.1 (K), U3.1 (D0)
ROW1: D2.1 (K), D4.1 (K), D7.1 (K), D10.1 (K), D13.1 (K), D16.1 (K), U3.2 (D1)
ROW2: D1.1 (K), D3.1 (K), D6.1 (K), D9.1 (K), D12.1 (K), D15.1 (K), U3.3 (D2)
ROW3: D18.1 (K), D19.1 (K), D20.1 (K), U3.4 (D3)
STS_LED_DATA: R712.2, TP2.1 (1_1), U3.21 (NFC1)
STS_LED_EN: R710.1, TP3.1 (1_1), U3.22 (NFC2)
VBAT: C1.1, C2.1, D25.2 (A), D26.2 (A), D29.2 (A), D30.2 (A), D31.2 (A), D32.2 (A), D33.2 (A), D34.2 (A), D35.2 (A), D36.2 (A), D37.2 (A), D38.2 (A), D39.2 (A), D40.2 (A), D41.2 (A), D42.2 (A), D43.2 (A), D44.2 (A), D45.2 (A), D46.2 (A), PSW1.3 (C), TP1.1 (1_1), U3.19 (VBAT)
VBAT_RAW: BT1.1 (+), JST1.1, PSW1.2 (B)

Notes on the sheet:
W O L F K B D
LOGO
MCU
LEDs can be turned off when STS_LED_EN = HIGH
RESET
Place C's near the power switch
Place Capacitors near the first LED in chain (PCB)
BACKLIGHT PWM MOSFET
POWER
STATUS LEDs
BACKLIGHT WHITE LEDS
SWITCH MATRIX

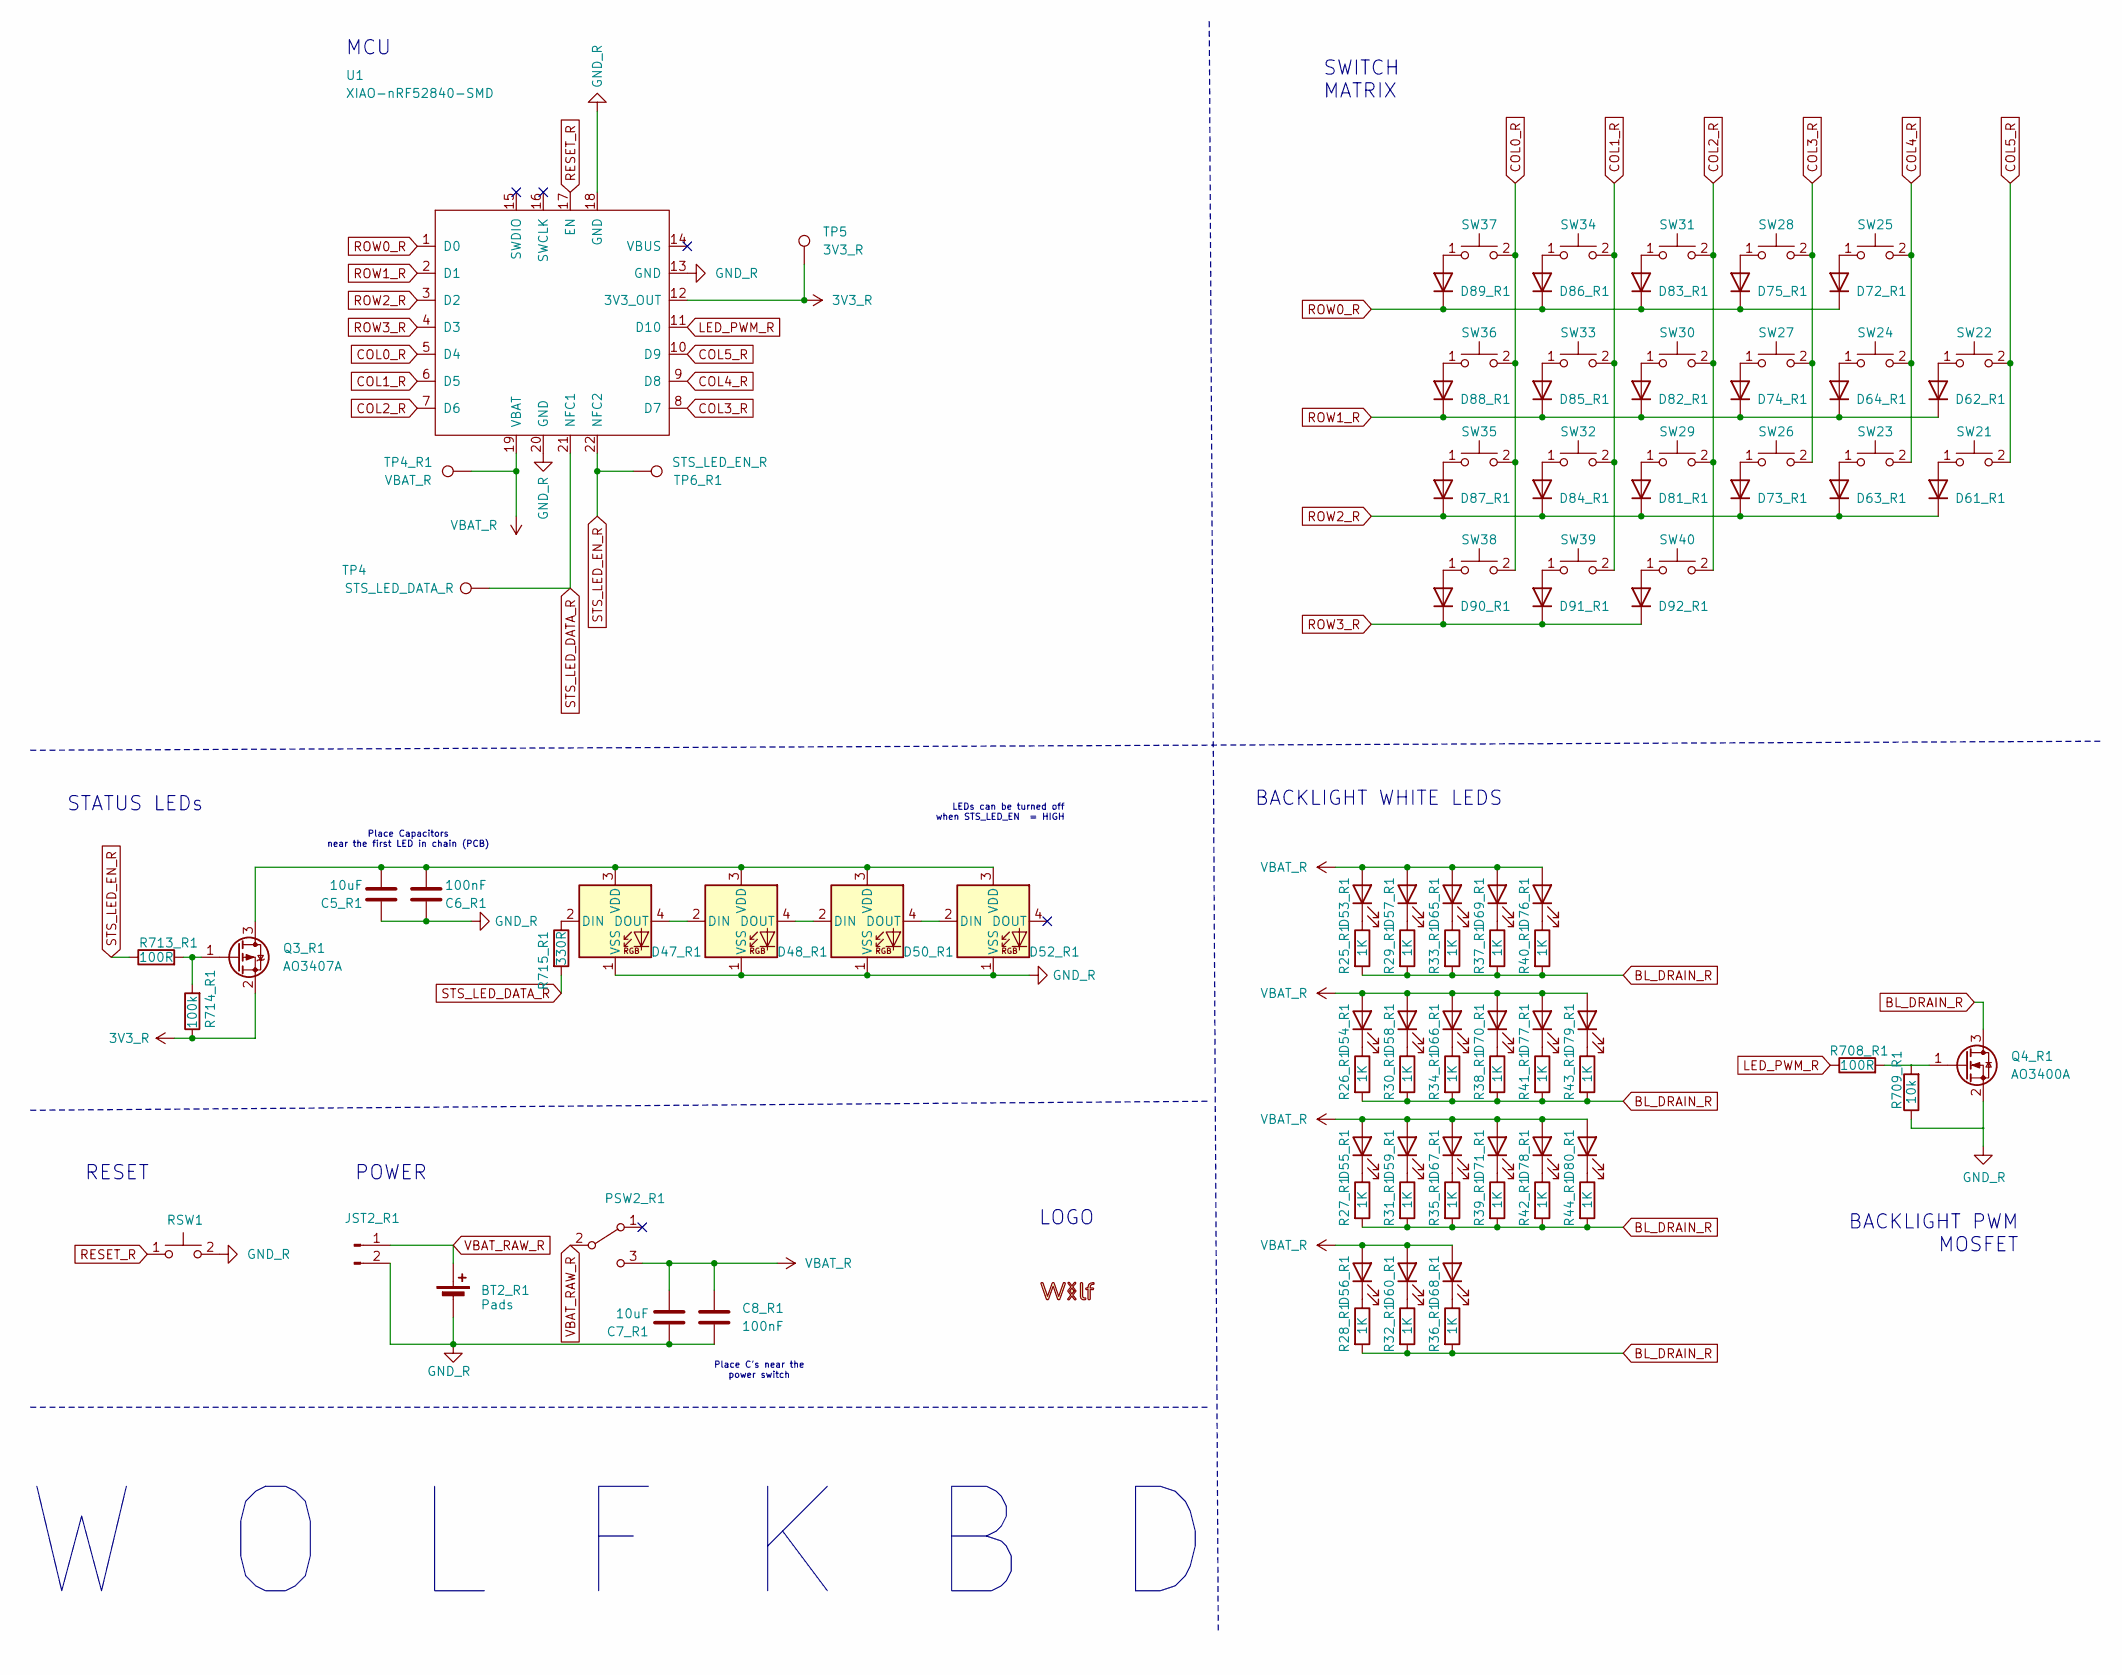
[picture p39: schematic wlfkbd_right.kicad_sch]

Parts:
3V3_R03, 3V3_R04: 3V3_R
BT2_R1: Pads; Battery_Pad
C5_R1, C7_R1: 10uF; C_0603_1608Metric
C6_R1, C8_R1: 100nF; C_0603_1608Metric
D47_R1, D48_R1, D50_R1, D52_R1: SK6812MINI-E; LED_SK6812MINI-E_3.2x2.8mm_P1.5mm_ReverseMount
D53_R1, D54_R1, D55_R1, D56_R1, D57_R1, D58_R1, D59_R1, D60_R1, D65_R1, D66_R1, D67_R1, D68_R1, D69_R1, D70_R1, D71_R1, D76_R1, D77_R1, D78_R1, D79_R1, D80_R1: LED; LED_MHT151WDT
D61_R1, D62_R1, D63_R1, D64_R1, D72_R1, D73_R1, D74_R1, D75_R1, D81_R1, D82_R1, D83_R1, D84_R1, D85_R1, D86_R1, D87_R1, D88_R1, D89_R1, D90_R1, D91_R1, D92_R1: 1N4148W; D_SOD-123
GND_R05, GND_R06, GND_R07, GND_R08, GND_R09: GND_R
JST2_R1: Conn_01x02_Pin; JST_GH_SM02B-GHS-TB_1x02-1MP_P1.25mm_Horizontal
LOGO_R1: Wolf Logo
PSW2_R1: SW_SPDT; SW_MSK12C02-HB
Q3_R1: AO3407A; SOT-23; MPN AO3407A
Q4_R1: AO3400A; SOT-23
R25_R1, R26_R1, R27_R1, R28_R1, R29_R1, R30_R1, R31_R1, R32_R1, R33_R1, R34_R1, R35_R1, R36_R1, R37_R1, R38_R1, R39_R1, R40_R1, R41_R1, R42_R1, R43_R1, R44_R1: 1K; R_0603_1608Metric
R708_R1, R713_R1: 100R; R_0603_1608Metric
R709_R1: 10k; R_0603_1608Metric
R714_R1: 100k; R_0603_1608Metric
R715_R1: 330R; R_0603_1608Metric
RSW2_R1: RSW1; SW_SPST_SKQG_WithStem
SW21, SW22, SW23, SW24, SW25, SW26, SW27, SW28, SW29, SW30, SW31, SW32, SW33, SW34, SW35, SW36, SW37, SW38, SW39, SW40: SW_Push; KS-33B Hotswap 1u
TP4: STS_LED_DATA_R; TestPoint_Pad_D1.0mm
TP4_R1: VBAT_R; TestPoint_Pad_D1.0mm
TP5: 3V3_R; TestPoint_Pad_D1.0mm
TP6_R1: STS_LED_EN_R; TestPoint_Pad_D1.0mm
U1: XIAO-nRF52840-SMD
VBAT_R01: VBAT_R

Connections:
BL_DRAIN_R: Q4_R1.3 (D), R25_R1.2, R26_R1.2, R27_R1.2, R28_R1.2, R29_R1.2, R30_R1.2, R31_R1.2, R32_R1.2, R33_R1.2, R34_R1.2, R35_R1.2, R36_R1.2, R37_R1.2, R38_R1.2, R39_R1.2, R40_R1.2, R41_R1.2, R42_R1.2, R43_R1.2, R44_R1.2
COL0_R: SW35.2, SW36.2, SW37.2, SW38.2, U1.5 (D4)
COL1_R: SW32.2, SW33.2, SW34.2, SW39.2, U1.6 (D5)
COL2_R: SW29.2, SW30.2, SW31.2, SW40.2, U1.7 (D6)
COL3_R: SW26.2, SW27.2, SW28.2, U1.8 (D7)
COL4_R: SW23.2, SW24.2, SW25.2, U1.9 (D8)
COL5_R: SW21.2, SW22.2, U1.10 (D9)
LED_PWM_R: R708_R1.1, U1.11 (D10)
unnamed: D47_R1.2 (DIN), R715_R1.1
unnamed: D47_R1.4 (DOUT), D48_R1.2 (DIN)
unnamed: C5_R1.2, C6_R1.1, D47_R1.3 (VDD), D48_R1.3 (VDD), D50_R1.3 (VDD), D52_R1.3 (VDD), Q3_R1.3 (D)
unnamed: D48_R1.4 (DOUT), D50_R1.2 (DIN)
unnamed: D50_R1.4 (DOUT), D52_R1.2 (DIN)
unnamed: D53_R1.1 (K), R25_R1.1
unnamed: D54_R1.1 (K), R26_R1.1
unnamed: D55_R1.1 (K), R27_R1.1
unnamed: D56_R1.1 (K), R28_R1.1
unnamed: D57_R1.1 (K), R29_R1.1
unnamed: D58_R1.1 (K), R30_R1.1
unnamed: D59_R1.1 (K), R31_R1.1
unnamed: D60_R1.1 (K), R32_R1.1
unnamed: D61_R1.2 (A), SW21.1
unnamed: D62_R1.2 (A), SW22.1
unnamed: D63_R1.2 (A), SW23.1
unnamed: D64_R1.2 (A), SW24.1
unnamed: D65_R1.1 (K), R33_R1.1
unnamed: D66_R1.1 (K), R34_R1.1
unnamed: D67_R1.1 (K), R35_R1.1
unnamed: D68_R1.1 (K), R36_R1.1
unnamed: D69_R1.1 (K), R37_R1.1
unnamed: D70_R1.1 (K), R38_R1.1
unnamed: D71_R1.1 (K), R39_R1.1
unnamed: D72_R1.2 (A), SW25.1
unnamed: D73_R1.2 (A), SW26.1
unnamed: D74_R1.2 (A), SW27.1
unnamed: D75_R1.2 (A), SW28.1
unnamed: D76_R1.1 (K), R40_R1.1
unnamed: D77_R1.1 (K), R41_R1.1
unnamed: D78_R1.1 (K), R42_R1.1
unnamed: D79_R1.1 (K), R43_R1.1
unnamed: D80_R1.1 (K), R44_R1.1
unnamed: D81_R1.2 (A), SW29.1
unnamed: D82_R1.2 (A), SW30.1
unnamed: D83_R1.2 (A), SW31.1
unnamed: D84_R1.2 (A), SW32.1
unnamed: D85_R1.2 (A), SW33.1
unnamed: D86_R1.2 (A), SW34.1
unnamed: D87_R1.2 (A), SW35.1
unnamed: D88_R1.2 (A), SW36.1
unnamed: D89_R1.2 (A), SW37.1
unnamed: D90_R1.2 (A), SW38.1
unnamed: D91_R1.2 (A), SW39.1
unnamed: D92_R1.2 (A), SW40.1
unnamed: Q3_R1.1 (G), R713_R1.2, R714_R1.2
unnamed: Q4_R1.1 (G), R708_R1.2, R709_R1.2
RESET_R: RSW2_R1.1, U1.17 (EN)
ROW0_R: D72_R1.1 (K), D75_R1.1 (K), D83_R1.1 (K), D86_R1.1 (K), D89_R1.1 (K), U1.1 (D0)
ROW1_R: D62_R1.1 (K), D64_R1.1 (K), D74_R1.1 (K), D82_R1.1 (K), D85_R1.1 (K), D88_R1.1 (K), U1.2 (D1)
ROW2_R: D61_R1.1 (K), D63_R1.1 (K), D73_R1.1 (K), D81_R1.1 (K), D84_R1.1 (K), D87_R1.1 (K), U1.3 (D2)
ROW3_R: D90_R1.1 (K), D91_R1.1 (K), D92_R1.1 (K), U1.4 (D3)
STS_LED_DATA_R: R715_R1.2, TP4.1 (1_1), U1.21 (NFC1)
STS_LED_EN_R: R713_R1.1, TP6_R1.1 (1_1), U1.22 (NFC2)
VBAT_RAW_R: BT2_R1.1 (+), JST2_R1.1, PSW2_R1.2 (B)

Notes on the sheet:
STATUS LEDs
SWITCH MATRIX
Place C's near the power switch
W O L F K B D
MCU
RESET
BACKLIGHT PWM MOSFET
LEDs can be turned off when STS_LED_EN = HIGH
LOGO
Place Capacitors near the first LED in chain (PCB)
BACKLIGHT WHITE LEDS
POWER

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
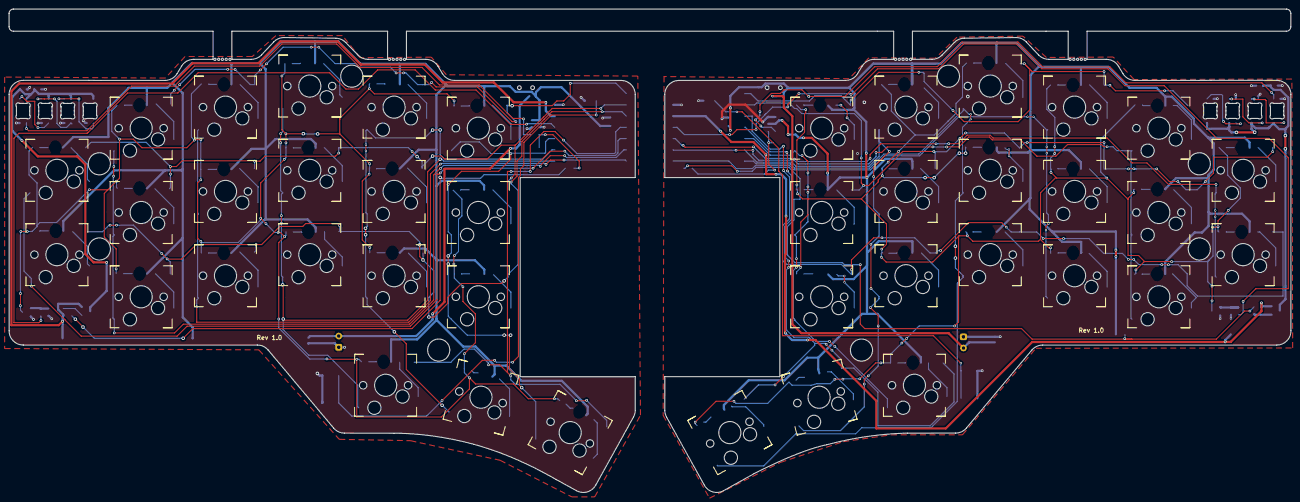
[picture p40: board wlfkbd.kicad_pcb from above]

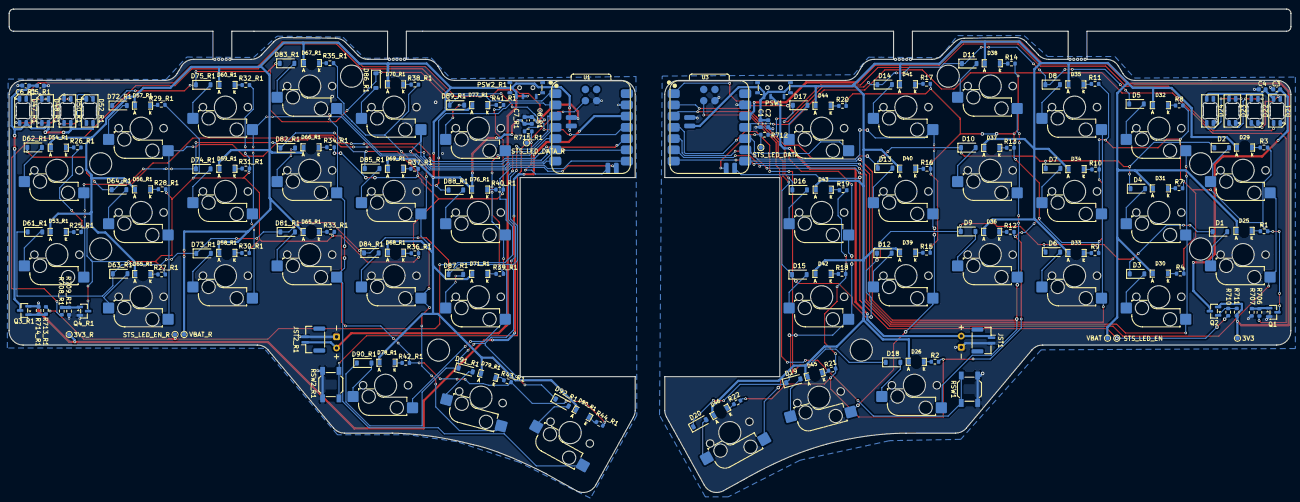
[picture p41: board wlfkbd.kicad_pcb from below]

Board: 2 copper layers, 289.7 x 109.2 mm, 210 parts (208 on the bottom side), 132 nets.

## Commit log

2026-08-29 feat: added 3d case models and renders
    [case_sketch.dxf, dormin.kicad_pcb, wlf_case_sketch.dxf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]
2026-08-29 feat: update full case 3d model
    [wlf_full_case.step]
2026-08-30 feat: added footprints | partial
    [dormin.kicad_pcb, dormin_left.kicad_sch]
2026-08-31 feat: organize footprints
    [dormin.kicad_pcb]
2026-08-31 chore: added temporary routing
    [dormin_.kicad_pcb, dormin_left.kicad_sch, dormin_right.kicad_sch]
2026-09-01 chore: finish main routing
    [dormin.kicad_pcb, dormin_left.kicad_sch, dormin_right.kicad_sch]
2026-09-01 chore: fix DRC errors
    [dormin.kicad_pcb]
2026-09-01 chore: update files and docs to reflect the kbd name
    [dormin.kicad_pcb, dormin.kicad_sch, dormin_.kicad_pcb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]
2026-09-01 feat: minor improvements to the routing
    [wlfkbd.kicad_pcb]
2026-09-01 feat: fix schematics after renaming files
    [wlfkbd.kicad_pcb, wlfkbd.kicad_sch]
2026-09-01 feat: added test points
    [wlfkbd.kicad_pcb, wlfkbd_left.kicad_sch, wlfkbd_right.kicad_sch]
2026-09-01 docs: improve README grammar, fixes, and add keyboard repo links
    [wlfkbd.kicad_pcb, wlfkbd_left.kicad_sch, wlfkbd_right.kicad_sch]
2026-09-07 chore: fix GND plane vias
    [wlfkbd.kicad_pcb]
2026-09-07 chore: fix traces and orgaize schematics
    [wlfkbd.kicad_pcb, wlfkbd.kicad_sch, wlfkbd_left.kicad_sch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]
2026-09-07 chore: update schematics
    [wlfkbd.kicad_pcb, wlfkbd_right.kicad_sch]
2026-09-07 feat: added mousebites
    [wlfkbd.kicad_pcb]
2026-09-08 feat: added production files
    [bom.csv, designators.csv, positions.csv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]
2026-09-08 feat: improve routing
    [bom.csv, wlfkbd.kicad_pcb]
2026-09-08 feat: remove unused components from BOM and POS
    [bom.csv, designators.csv, positions.csv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]
2026-09-08 feat: fix bom and positions components list
    [bom.csv, designators.csv, positions.csv]
2026-09-09 feat: updated switch footprint with 3d models
    [wlfkbd.kicad_pcb]
2026-09-09 refactor: remove logo silkscreen from board
2026-09-09 refactor: improve traces routing
    [wlfkbd.kicad_pcb]
2026-09-09 refactor: fix minor DRC issues
    [wlfkbd.kicad_pcb]
2026-09-09 chore: update gerbers
2026-09-13 chore: update firmware submodule pointer with status LED config
2026-09-19 feat: remove old pcb files
    [dormin.kicad_pcb, dormin.kicad_sch, dormin_left.kicad_sch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]
2026-09-19 chore: remove unused files
    [dormin_42_key_outline.kicad_pcb, dormin_routed_demo.kicad_pcb, dormin_u_col.kicad_pcb]
2026-10-04 chore: update kicad project file
2026-10-05 docs: update docs and organize files
    [designators.csv, wlf_full_case.step, wlf_led_diffuser.step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]
